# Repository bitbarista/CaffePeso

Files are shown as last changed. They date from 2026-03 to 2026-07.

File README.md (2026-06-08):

# CaffePeso ☕

> [!NOTE]
> **This project is under active development.** Features and hardware design may evolve.
> Feedback and contributions welcome.

<div align="center">

### *Weigh smarter. Pull better.*





**A smart, automated espresso scale with a web interface — no custom PCBs required.**

Armed auto-start • Auto-stop • Smart switch • Live brew ratio • Shot history • Target yield alert • GaggiMate BLE • Beanconqueror BLE • Wi-Fi web UI

[Features](#-features) • [Hardware](#️-hardware) • [3D Print Files](#-3d-print-files) • [Installation](#-installation) • [Documentation](#-documentation) • [Attribution](#-attribution)

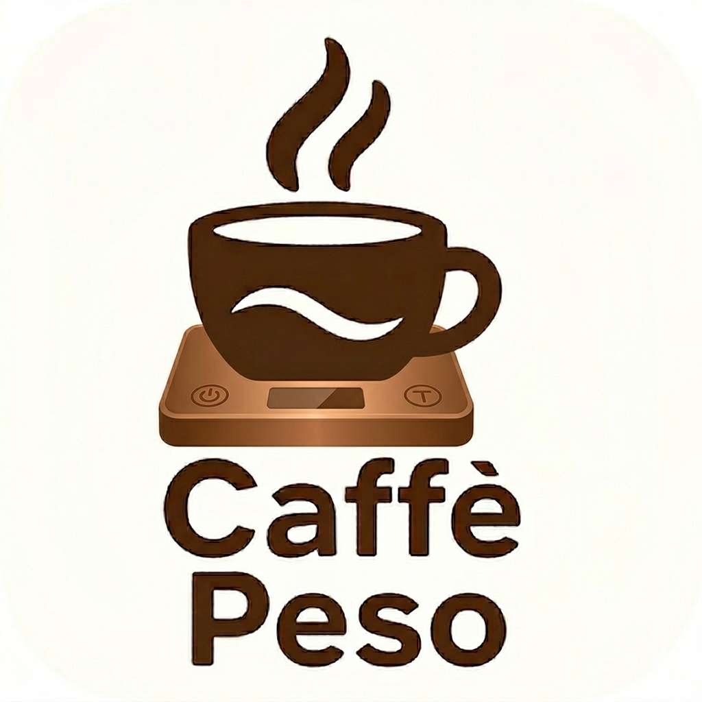
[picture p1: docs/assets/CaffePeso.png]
CaffePeso


</div>

---

## 📖 What is CaffePeso?

CaffePeso is a fork of [WeighMyBru²](https://github.com/031devstudios/weighmybru2) by 031DevStudios, adding brewing automation to an already excellent DIY espresso scale. It runs on an ESP32-S3 and hosts its own web interface over Wi-Fi — no external server or hub required.

It is designed to work alongside [GaggiMate](https://github.com/jniebuhr/gaggimate) via Bluetooth, or as a standalone scale. Inspired by the [EspressiScale](https://www.espressiscale.com) approach, but built from easily sourceable off-the-shelf parts — no custom PCBs.

---

## 📸 Screenshots

<table>
  <tr>
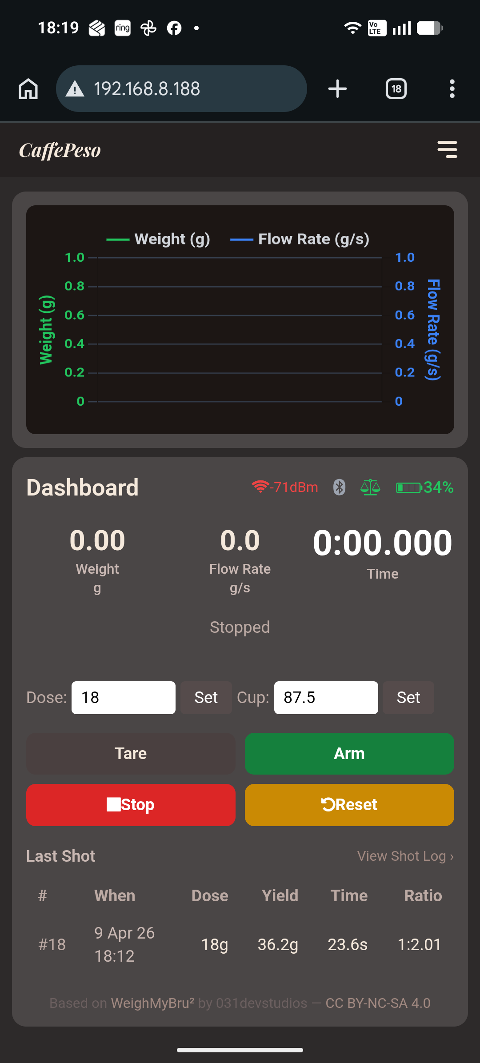
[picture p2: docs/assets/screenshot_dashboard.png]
    <td align="center"><br/><sub>Dashboard</sub></td>
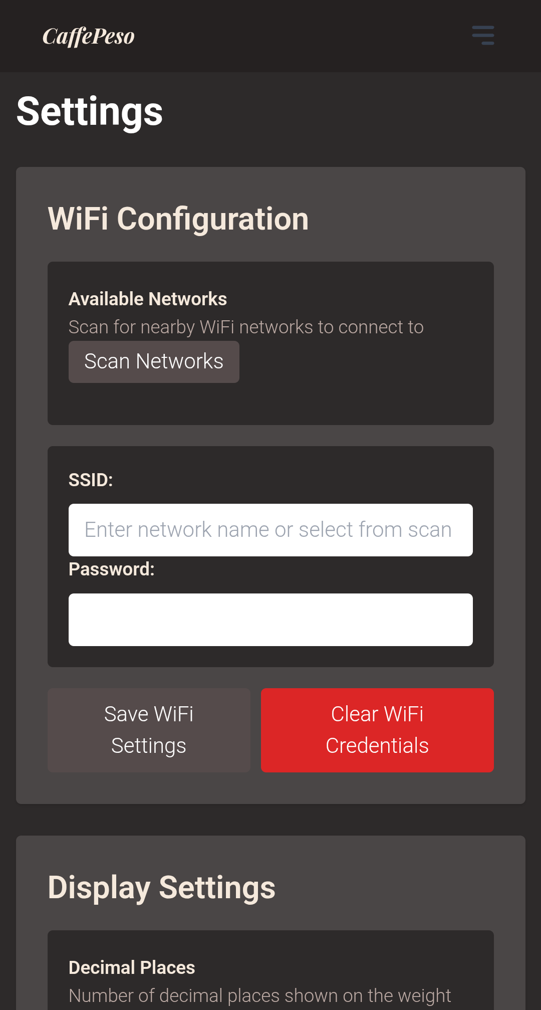
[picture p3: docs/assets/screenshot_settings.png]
    <td align="center"><br/><sub>Settings</sub></td>
  </tr>
  <tr>
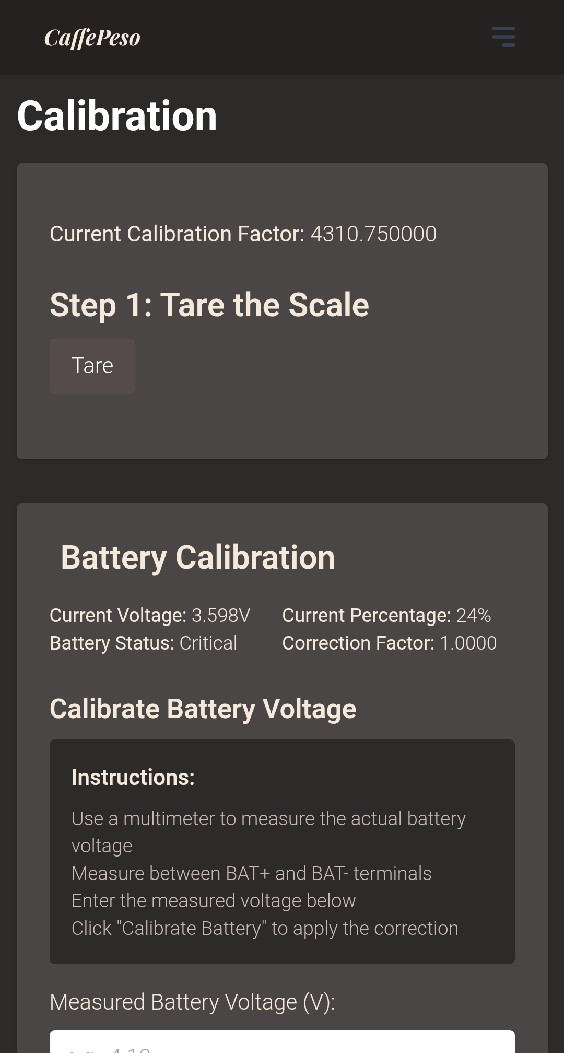
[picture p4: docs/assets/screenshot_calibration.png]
    <td align="center"><br/><sub>Calibration</sub></td>
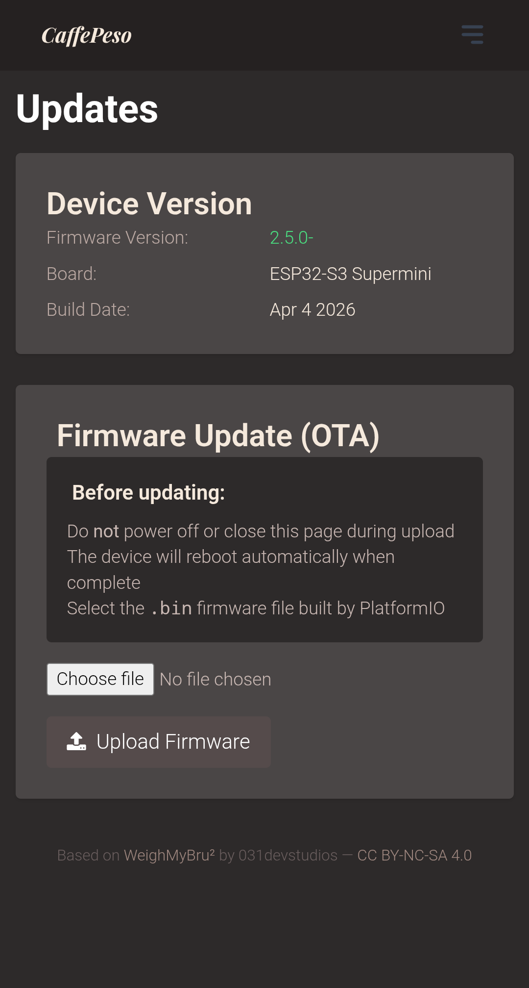
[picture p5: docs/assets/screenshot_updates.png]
    <td align="center"><br/><sub>Updates</sub></td>
  </tr>
  <tr>
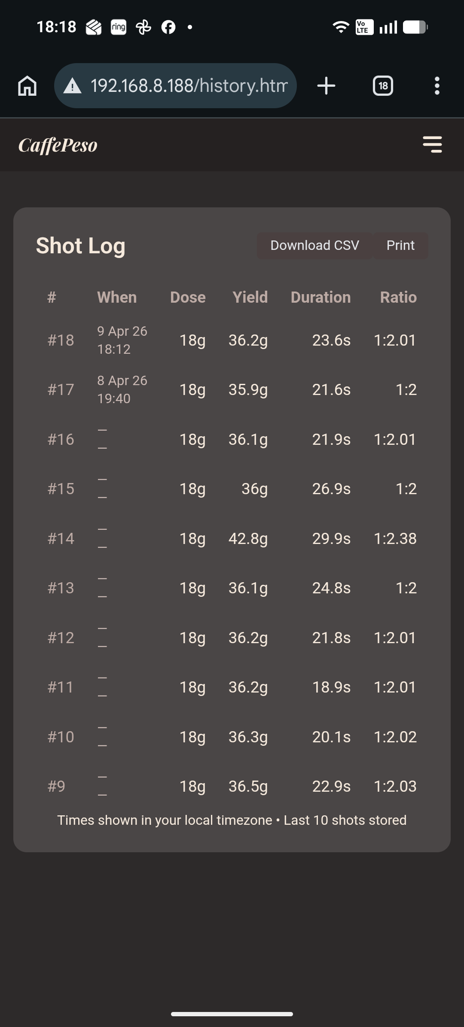
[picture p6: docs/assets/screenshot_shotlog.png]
    <td align="center"><br/><sub>Shot Log</sub></td>
  </tr>
</table>

---

## ✨ Features

### ⏱️ Armed Auto-Start
Hold tare to arm the scale before your shot. The timer starts automatically when the first drip hits the cup — no button press needed at the machine.

### 🔄 Auto-Re-Arm
The scale remembers your cup weight. On the next shot, place the same cup and tap tare — it recognises the cup and arms itself automatically.

### 📊 Live Brew Ratio
Set your dose once. The OLED displays a live 1:X ratio as yield builds in the cup, so you always know where you are in the extraction.

### 🔔 Target Yield Alert
Configure a target ratio (e.g. 1:2.0). When yield approaches your target, the OLED flashes and the web UI turns amber — giving you time to stop the shot.

### 🔊 Audible Beeps (Piezo Buzzer)
An optional piezo buzzer adds sound to the key moments — tare, armed/re-armed, target yield reached, smart-switch stop, low battery, and Bluetooth connect/disconnect. Every beep is individually toggleable in **Settings → Sound**, so you can keep just the cues you want. This is an optional add-on that requires fitting the piezo (see the [wiring guide](docs/USER_GUIDE.md#24-wiring)); CaffePeso is fully functional without it.

### 📜 Shot History
The last 10 shots are automatically saved to non-volatile memory: dose, yield, time, and ratio. Survives reboots and power loss. Displayed in the web UI dashboard.

### 📱 Wi-Fi Web Interface
A full dashboard hosted directly on the ESP32-S3 — calibration, settings, shot history, OTA firmware updates, and real-time graphs. No app required.

### 🛑 Auto-Stop on Flow Cessation

Once flow has been active for at least 8 seconds, the timer stops automatically when flow drops below 0.5 g/s and remains there for 2 seconds. No manual stop needed at the end of a shot.

### 🔌 Smart Switch (Shelly Integration)

> **⚠️ Safety notice:** This feature requires fitting a Shelly relay into your machine's mains electrical circuit. This work involves mains voltage and must only be carried out by a competent person who understands the risks. The authors of this project accept no liability for damage, injury, or death arising from electrical work carried out in connection with this feature. **This is entirely optional — CaffePeso is fully functional without it.**

CaffePeso can automatically stop your espresso machine by controlling a [Shelly](https://www.shelly.com) smart relay fitted inline with the pump or solenoid valve. This does require electrical work inside the machine and should only be carried out by a competent person.

When armed with a dose and target ratio, CaffePeso monitors weight and flow rate during the shot and fires a relay-off command when the projected final yield is about to hit the target:

```
trigger = target_weight − (flow_rate × after_stop_time)
```

The **After-Stop Time (AST)** — the seconds of drip after the pump cuts — is learned automatically from each shot and stored per dose/ratio combination, improving accuracy over time.

A **post-trigger safety interlock** keeps the relay off until you perform a hold-tare, preventing the pump accidentally restarting between shots.

See [Section 14 of the User Guide](docs/USER_GUIDE.md#14-smart-switch-shelly-integration) for setup instructions.

### 🔵 Bluetooth Scale Support
Native Bluetooth scale support for [GaggiMate](https://github.com/jniebuhr/gaggimate) and [Beanconqueror](https://beanconqueror.com). CaffePeso uses the same BLE protocol as WeighMyBru² — GaggiMate's existing WeighMyBru support works with CaffePeso without any changes on either side. Beanconqueror can connect to CaffePeso for real-time weight, tare, and timer control.

---

## 🛠️ Hardware

The hardware is identical to the original WeighMyBru² project. See the [original WeighMyBru² repository](https://github.com/031devstudios/weighmybru2) for:
- Bill of Materials (BOM) with purchase links
- Wiring guides and pin assignments

**Supported boards:**
- ESP32-S3 SuperMini (4 MB flash) — default
- XIAO ESP32S3 (8 MB flash)

---

## 🖨️ 3D Print Files

All enclosure files are included in this repository and available as a single download — no need to navigate anywhere else.



The ZIP contains:

| File | Purpose |
|---|---|
| `WeighMyBru² - Top.3mf` | Main lid — standard walls |
| `WeighMyBru² - Top (0.8mm).3mf` | Main lid — 0.8 mm walls |
| `WeighMyBru² - Bottom.3mf` | Base |
| `WeighMyBru² - Bottom Supported.3mf` | Base, with print supports |
| `WeighMyBru² - Bottom - Piezo.3mf` | Base, piezo cutout — *optional* |
| `WeighMyBru² - ESP32 Clamp.3mf` | ESP32-S3 SuperMini clamp |
| `WeighMyBru² - XAIO Clamp.3mf` | XIAO ESP32S3 clamp |
| `WeighMyBru² - Screen Clamp.3mf` | OLED display clamp |
| `WeighMyBru² - Touch Clamp.3mf` | Touch button clamp |
| `WeighMyBru² - M2 Washer.3mf` | M2 washer spacer |

Most `.3mf` files also have a matching `.step` file for editing in CAD software.

> These files are from the [WeighMyBru²](https://github.com/031devstudios/weighmybru2) project by 031DevStudios and are licensed under [CC BY-NC-SA 4.0](https://creativecommons.org/licenses/by-nc-sa/4.0/).

---

## 📦 Installation

### 🌐 Web-Based (Recommended)

No software installation required — flash directly from your browser:

1. Visit the [flash page](https://bitbarista.github.io/CaffePeso/flash.html)
2. Connect your ESP32 board via USB
3. Click **Install Firmware** and select your board
4. Follow the prompts

✅ No VS Code or PlatformIO needed
✅ Installs firmware + filesystem in one step
✅ Works on Chrome, Edge, and Opera

### 🔧 PlatformIO (Advanced)

Requires VS Code with the PlatformIO extension.

```bash
# Upload firmware (default: esp32s3-supermini)
pio run --target upload

# Upload filesystem (required for web interface)
pio run --target uploadfs

# For XIAO ESP32S3 explicitly:
pio run -e esp32s3-xiao --target upload
pio run -e esp32s3-xiao --target uploadfs
```

> **Important:** Always flash firmware and filesystem using the same environment. Flashing the wrong environment (e.g. xiao firmware onto a supermini) causes a boot crash due to flash size mismatch (4 MB vs 8 MB).

---

## 📚 Documentation

Full user guide: [docs/USER_GUIDE.md](docs/USER_GUIDE.md)

For hardware build guides and video walkthroughs, see the [original project](https://github.com/031devstudios/weighmybru2).

---

## 🤝 Contributing

Contributions welcome — bug fixes, features, and documentation improvements are all appreciated. Please test your changes before submitting a pull request.

---

## 📜 Attribution

This project is a derivative of [WeighMyBru²](https://github.com/031devstudios/weighmybru2) by 031devstudios, licensed under [CC BY-NC-SA 4.0](https://creativecommons.org/licenses/by-nc-sa/4.0/).

Additions in this fork:
- CaffePeso branding — dark warm-brown web UI theme, Playfair Display italic title, OLED splash
- Armed auto-start: hold tare to arm; timer triggers on first drip; auto-re-arms when same cup detected
- Live OLED brew ratio during extraction
- Target yield alert: OLED flashes and web UI turns amber when approaching target ratio
- Cup weight persistence across reboots (NVS)
- Shot history: last 10 shots stored in NVS, displayed in web UI
- Power button redesigned: tap cycles timer (start → pause → reset); hold 1 s = status page; hold 3 s = sleep
- Wi-Fi always-on: toggle removed; device deep-sleeps to save power instead
- Auto-stop on flow cessation: timer stops automatically when espresso flow ends
- Auto-tare on vessel placement: tares automatically when a stable weight is detected (configurable threshold)
- Post-brew idle reset: auto-resets and re-tares after a configurable idle period
- Arm button in web UI: arm/disarm directly from the dashboard without touching the physical button
- Smart switch: predictive Shelly relay control to stop the machine at target yield, with per-dose AST learning and post-trigger safety interlock

This derivative is also released under [CC BY-NC-SA 4.0](https://creativecommons.org/licenses/by-nc-sa/4.0/).

---

## ⚖️ Disclaimer

This project is provided "AS IS" without warranty of any kind. The author makes no representations about suitability, reliability, or fitness for any purpose. Your use is entirely at your own risk. The author shall not be liable for any damages arising from use, including but not limited to direct, indirect, incidental, or consequential damages.

---

## 🙏 Acknowledgments

- **[WeighMyBru²](https://github.com/031devstudios/weighmybru2)** by 031devstudios — the hardware design and original firmware this project is built on (CC BY-NC-SA 4.0)
- **[GaggiMate](https://github.com/jniebuhr/gaggimate)** by jniebuhr — for native BLE scale support
- **[EspressiScale](https://www.espressiscale.com)** — inspiration for the approach

---

<div align="center">

**Built with ☕ by a home espresso enthusiast**

*Not affiliated with any espresso machine manufacturer*

</div>

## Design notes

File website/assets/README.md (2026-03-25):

# Website Assets

This directory contains images and other assets for the CaffePeso website.

## Required Files

Please add these image files to this directory:

### Board Images
- `supermini-board.jpg` - Photo of ESP32-S3 Supermini board (recommended: 400x300px)
- `xiao-board.jpg` - Photo of XIAO ESP32S3 board (recommended: 400x300px)

### Branding
- `logo.png` - CaffePeso logo (recommended: 128x128px or larger)
- `favicon.ico` - Website favicon (16x16px, 32x32px)

## Image Guidelines

### Board Photos
- Use clear, well-lit photos showing the board clearly
- White or light background preferred
- Show the USB connector and any relevant markings
- Crop to focus on the board itself

### Logo
- Transparent background PNG preferred
- High resolution for scalability
- Should work on both light and dark backgrounds

## Optimization

Before uploading to your website, consider optimizing images:

```bash
# Using imagemagick to optimize
convert supermini-board.jpg -quality 85 -resize 400x300 supermini-board.jpg
convert xiao-board.jpg -quality 85 -resize 400x300 xiao-board.jpg

# Using webp for better compression (optional)
cwebp -q 85 supermini-board.jpg -o supermini-board.webp
cwebp -q 85 xiao-board.jpg -o xiao-board.webp
```

## Fallbacks

If you don't have actual board photos yet, you can:

1. Use placeholder images with the board names
2. Find Creative Commons images online
3. Use manufacturer product photos (check licensing)
4. Generate simple graphics with the board names

The website will still function without images - they'll show as empty placeholders.

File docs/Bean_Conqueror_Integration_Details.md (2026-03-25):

# CaffePeso - Bean Conqueror Integration Details

## Current BLE Implementation for Bean Conqueror Integration

### Advertising Information
- **Device Name**: `CaffePeso`
- **Advertising**: Device advertises continuously when not connected

### Service and Characteristic UUIDs
- **Service UUID**: `6E400001-B5A3-F393-E0A9-E50E24DCCA9E`
- **GaggiMate Weight Characteristic UUID**: `6E400002-B5A3-F393-E0A9-E50E24DCCA9E`
  - Properties: READ, NOTIFY, INDICATE
  - Used for: GaggiMate weight data (CaffePeso protocol format)
- **Command Characteristic UUID**: `6E400003-B5A3-F393-E0A9-E50E24DCCA9E`
  - Properties: WRITE, WRITE_NR, NOTIFY
  - Used for: Receiving commands from both apps (tare, timer control)
- **Bean Conqueror Weight Characteristic UUID**: `6E400004-B5A3-F393-E0A9-E50E24DCCA9E`
  - Properties: READ, NOTIFY, INDICATE
  - Used for: Bean Conqueror weight data (simple float format)

### Required API Functions - Implementation Status

#### ✅ Weight Send
- **Status**: ✅ IMPLEMENTED
- **Frequency**: 50ms interval (20 updates/second)
- **Format**: CaffePeso protocol with weight data in grams
- **Precision**: Floating point weight values

#### ✅ Taring
- **Status**: ✅ IMPLEMENTED
- **Command Code**: `0x01`
- **Protocol**: Send `[0x03, 0x0A, 0x01, 0x01, 0x00]` to command characteristic
- **Response**: Confirmation message sent back via weight characteristic
- **Function**: Zeros the scale reading

#### ✅ Timer Start
- **Status**: ✅ IMPLEMENTED
- **Command Code**: `0x02`
- **Protocol**: Send `[0x03, 0x0A, 0x02, 0x01, 0x00]` to command characteristic
- **Response**: Start confirmation `[0x03, 0x0A, 0x02, 0x01, 0x00]`
- **Function**: Starts the brewing timer on CaffePeso

#### ✅ Timer Stop
- **Status**: ✅ IMPLEMENTED
- **Command Code**: `0x03`
- **Protocol**: Send `[0x03, 0x0A, 0x03, 0x01, 0x00]` to command characteristic
- **Response**: Stop confirmation `[0x03, 0x0A, 0x03, 0x01, 0x00]`
- **Function**: Stops the brewing timer on CaffePeso

#### ✅ Timer Reset
- **Status**: ✅ IMPLEMENTED
- **Command Code**: `0x04`
- **Protocol**: Send `[0x03, 0x0A, 0x04, 0x01, 0x00]` to command characteristic
- **Response**: Reset confirmation `[0x03, 0x0A, 0x04, 0x01, 0x00]`
- **Function**: Resets the brewing timer to 0:00.000

## Protocol Details

### Command Message Format
```
[Product_ID, Message_Type, Command, Trigger, Reserved]
```
- **Product_ID**: `0x03` (CaffePeso identifier)
- **Message_Type**: `0x0A` (System command)
- **Command**: Command code (0x01-0x04)
- **Trigger**: `0x01` (Execute command)
- **Reserved**: `0x00` (Future use)

### Weight Data Format
- Sent via weight characteristic notifications
- **Format**: Simple 4-byte float in little-endian byte order
- **Data**: Weight value directly in grams (e.g., 15.67g)
- **Precision**: Full floating-point precision
- **Update Rate**: Automatic notifications every 50ms when connected
- **Byte Layout**: `[float32_little_endian]` (4 bytes total)

### Connection Behavior
- Automatically starts advertising when disconnected
- Stops advertising when connected
- Supports single client connection
- Automatic reconnection support

## Integration Notes for Bean Conqueror

1. **Discovery**: Look for device named "CaffePeso" in BLE scan
2. **Connection**: Connect to service UUID `6E400001-B5A3-F393-E0A9-E50E24DCCA9E`
3. **Weight Subscription**: Subscribe to notifications on `6E400004-B5A3-F393-E0A9-E50E24DCCA9E` (Bean Conqueror specific)
4. **Command Sending**: Write commands to `6E400003-B5A3-F393-E0A9-E50E24DCCA9E`
5. **Timer Control**: All timer functions (start/stop/reset) are available via BLE

### Important: Dual App Support
CaffePeso supports **both Bean Conqueror and GaggiMate simultaneously**:

**Bean Conqueror**:
- Weight data: `6E400004-...` (4-byte float32 little-endian)
- Expected format: Simple float value in grams

**GaggiMate**:
- Weight data: `6E400002-...` (20-byte CaffePeso protocol)
- Expected format: Full protocol with headers and checksums

**Commands**: Both apps share `6E400003-...` for tare and timer commands

## Technical Specifications

- **Platform**: ESP32-S3
- **BLE Stack**: ESP32 Arduino BLE library
- **Update Rate**: 20Hz (50ms intervals)
- **Weight Range**: 0-5000g (depending on load cell)
- **Precision**: 0.1g
- **Timer Precision**: Millisecond accuracy
- **Connection**: Single client BLE connection
- **Power**: Battery operated with monitoring

## Example Usage

```javascript
// Connect to CaffePeso
const device = await navigator.bluetooth.requestDevice({
  filters: [{name: 'CaffePeso'}],
  optionalServices: ['6E400001-B5A3-F393-E0A9-E50E24DCCA9E']
});

// Subscribe to weight notifications
const weightChar = await service.getCharacteristic('6E400002-B5A3-F393-E0A9-E50E24DCCA9E');
await weightChar.startNotifications();

// Send tare command
const commandChar = await service.getCharacteristic('6E400003-B5A3-F393-E0A9-E50E24DCCA9E');
await commandChar.writeValue(new Uint8Array([0x03, 0x0A, 0x01, 0x01, 0x00]));

// Send timer start command
await commandChar.writeValue(new Uint8Array([0x03, 0x0A, 0x02, 0x01, 0x00]));
```

## Relevant Source Files

- `include/BluetoothScale.h` - BeanConquerorCommand enum and method declarations
- `src/BluetoothScale.cpp` - Weight streaming and command handling implementation
- `src/main.cpp` - Display reference for timer control

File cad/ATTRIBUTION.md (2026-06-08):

---
**3D Enclosure Files — Attribution Notice**

These CAD files are sourced from the [WeighMyBru²](https://github.com/031devstudios/weighmybru2) project by [031DevStudios](https://github.com/031devstudios).

Except where noted below, they are reproduced here unchanged for ease of access and are licensed under the same terms as the original:

**[Creative Commons Attribution-NonCommercial-ShareAlike 4.0 International (CC BY-NC-SA 4.0)](https://creativecommons.org/licenses/by-nc-sa/4.0/)**

You are free to share and adapt these files for non-commercial purposes, provided you give appropriate credit and distribute any derivatives under the same licence.

**Modifications:**

- `WeighMyBru² - Bottom - Piezo.3mf` is a derivative of the original `Bottom` model, modified for the CaffePeso project to add a cutout for the optional piezo buzzer. It is shared under the same CC BY-NC-SA 4.0 licence.

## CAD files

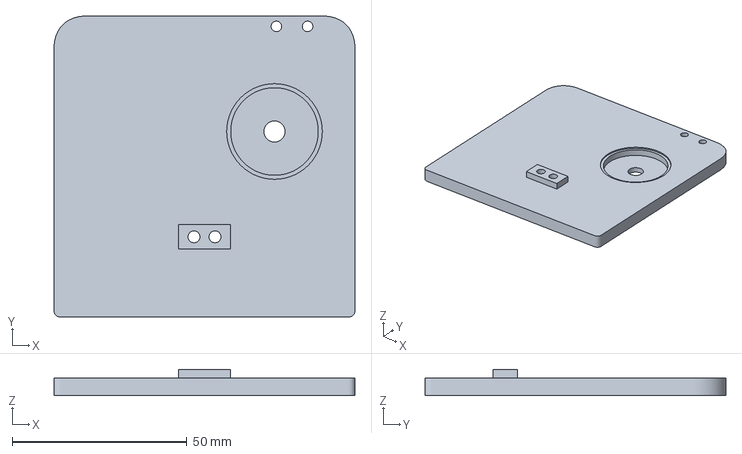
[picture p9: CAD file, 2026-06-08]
cad/3mf/WeighMyBru² - Bottom - Piezo.3mf
86.0 x 86.0 x 7.50 mm

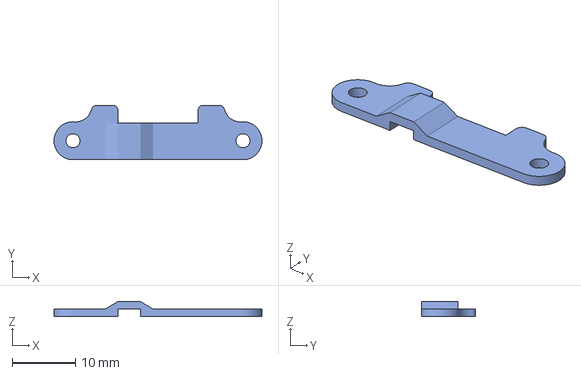
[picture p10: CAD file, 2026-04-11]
cad/3mf/WeighMyBru² - XAIO Clamp.3mf
32.8 x 8.60 x 2.40 mm

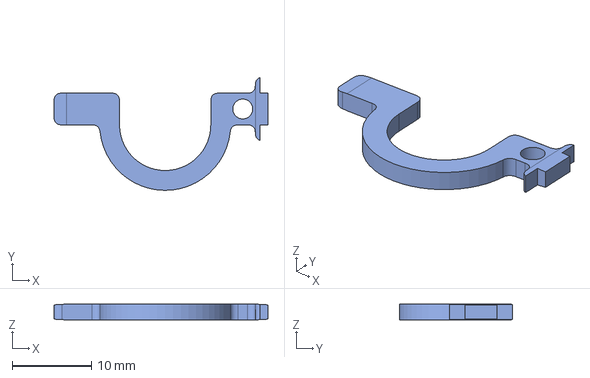
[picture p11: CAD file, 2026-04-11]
cad/step/WeighMyBru² - Touch Clamp.step
26.9 x 14.2 x 2.00 mm

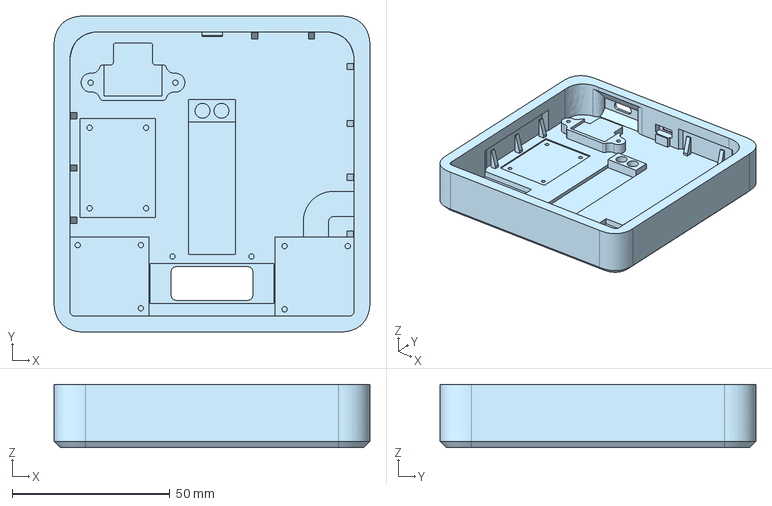
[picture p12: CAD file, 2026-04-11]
cad/step/WeighMyBru² - Top.step
100.0 x 100.0 x 20.0 mm

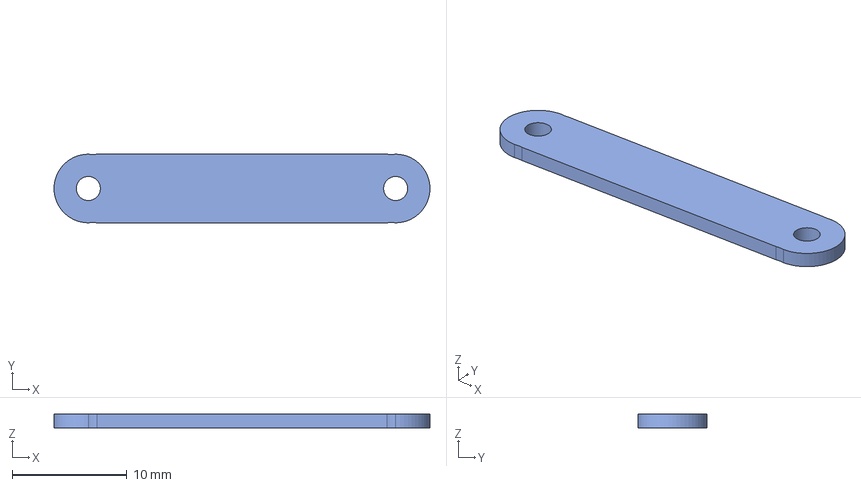
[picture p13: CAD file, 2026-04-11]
cad/step/WeighMyBru² - ESP32 Clamp.step
32.8 x 6.00 x 1.20 mm

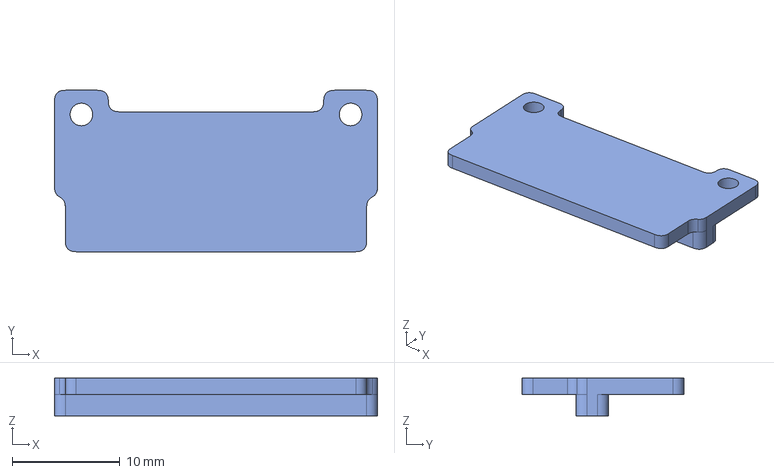
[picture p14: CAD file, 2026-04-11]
cad/step/WeighMyBru² - Screen Clamp.step
30.0 x 15.0 x 3.50 mm

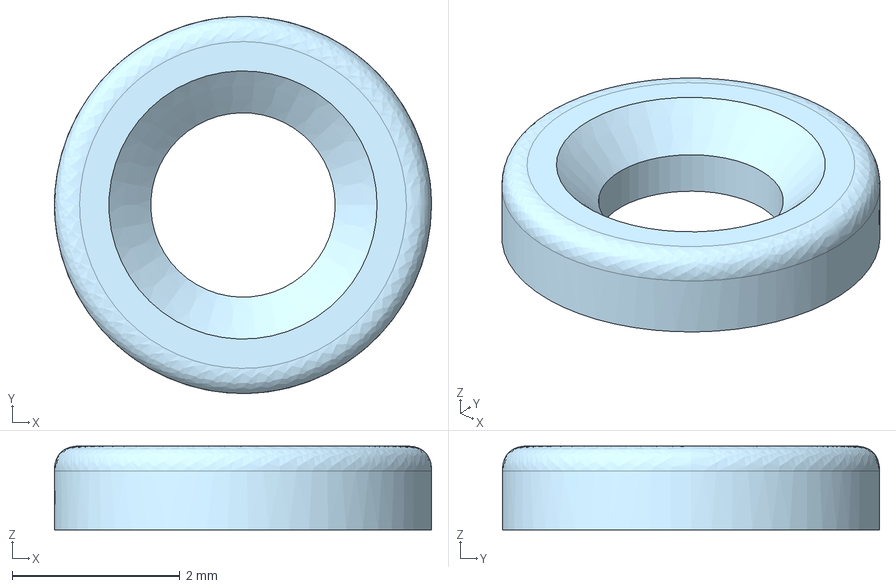
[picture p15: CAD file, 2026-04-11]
cad/step/WeighMyBru² - M2 Washer.step
4.50 x 4.50 x 1.00 mm

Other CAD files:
cad/step/WeighMyBru² - Bottom Supported.step
cad/step/WeighMyBru² - Top (0.8mm).step
cad/step/WeighMyBru² - Bottom.step
cad/3mf/WeighMyBru² - Bottom Supported.3mf
cad/3mf/WeighMyBru² - Bottom.3mf
cad/3mf/WeighMyBru² - ESP32 Clamp.3mf
cad/3mf/WeighMyBru² - M2 Washer.3mf
cad/3mf/WeighMyBru² - Screen Clamp.3mf
cad/3mf/WeighMyBru² - Top (0.8mm).3mf
cad/3mf/WeighMyBru² - Top.3mf
cad/3mf/WeighMyBru² - Touch Clamp.3mf

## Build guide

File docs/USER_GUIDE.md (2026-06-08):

# CaffePeso User Guide

**Version 2.4.3**

---

*Weigh smarter. Pull better.*

---

## Table of Contents

1. [Introduction](#1-introduction)
2. [Hardware Overview](#2-hardware-overview)
3. [First-Time Setup](#3-first-time-setup)
4. [Physical Controls](#4-physical-controls)
5. [OLED Display](#5-oled-display)
6. [Web Interface](#6-web-interface)
7. [Brewing Workflows](#7-brewing-workflows)
8. [Brew Automation Features](#8-brew-automation-features)
9. [Settings Reference](#9-settings-reference)
10. [Calibration](#10-calibration)
11. [Firmware Updates](#11-firmware-updates)
12. [Power and Battery](#12-power-and-battery)
13. [GaggiMate Bluetooth Integration](#13-gaggimate-bluetooth-integration)
14. [Smart Switch (Shelly Integration)](#14-smart-switch-shelly-integration)
15. [Troubleshooting](#15-troubleshooting)

---

## 1. Introduction

CaffePeso is a smart espresso scale built on the ESP32-S3 microcontroller. It combines a precision load cell, a live OLED display, and a Wi-Fi web interface to give you real-time weight, flow rate, timer, and brew ratio — all in a compact, battery-powered unit that sits under your cup.

It is designed to work seamlessly at the espresso machine without requiring a phone or app. Every parameter you need to pull a consistent shot is either visible on the OLED or accessible through a browser on your home network.

**Key capabilities:**

- Real-time weight display with configurable decimal places
- Brew timer with automatic start on first drip (armed auto-start)
- Live flow rate (g/s) and brew ratio (1:X)
- Target yield alert — OLED flashes when approaching your target
- Shot history — last 10 shots stored through power cycles
- Cup weight auto re-arm — recognises your cup and arms itself for the next shot
- Auto-tare on vessel placement
- Auto-stop when espresso flow ceases
- Wi-Fi web interface with real-time graph, calibration, settings, and OTA updates
- GaggiMate Bluetooth scale compatibility

---

## 2. Hardware Overview

### 2.1 Supported Boards

| Board | Flash | Notes |
|---|---|---|
| ESP32-S3 SuperMini | 4 MB | Default — recommended |
| XIAO ESP32S3 | 8 MB | Alternative |

### 2.2 Pin Assignments

| Function | GPIO | Notes |
|---|---|---|
| HX711 Data | 5 | Load cell amplifier data |
| HX711 Clock | 6 | Load cell amplifier clock |
| Tare button | 4 | Capacitive touch module |
| Sleep/timer button | 3 | Capacitive touch module |
| Battery voltage | 7 | ADC via 2× 100 kΩ voltage divider |
| I²C SDA (display) | 8 | SSD1306 OLED |
| I²C SCL (display) | 9 | SSD1306 OLED |

### 2.3 Bill of Materials

| Qty | Component |
|-----|---|
| 1 | 500 g I-shaped mini load cell |
| 1 | HX711 load cell amplifier module |
| 1 | ESP32-S3 SuperMini (or XIAO ESP32S3) |
| 1 | 0.91″ SSD1306 OLED display (128×32, I²C) |
| 2 | Capacitive touch pad modules |
| 1 | 800 mAh Li-ion battery |
| 1 | JST-PH 2.0 male connector |
| 1 | 5 mm slide switch (power) |
| 2 | 100 kΩ 1% resistors (battery voltage divider) |
| 1 | 27 mm piezo disc (~4.2 kHz resonant) — *optional* |
| 2 | 150 Ω resistors (piezo series, one per lead) — *optional* |
| 4 | Self-adhesive rubber feet |

Purchase links for all components are available in the [WeighMyBru² repository](https://github.com/031devstudios/weighmybru2) — the hardware is identical.

### 2.4 Wiring

GPIO pin numbers are identical on both supported boards. The physical pin *locations* differ — refer to the pinout diagram for your specific board when connecting wires.

#### HX711 Load Cell Amplifier

| HX711 Pin | Connect to |
|---|---|
| VCC | 3.3 V |
| GND | GND |
| DT | GPIO 5 |
| SCK | GPIO 6 |

Connect the load cell wires to the HX711 E+/E−/A+/A− terminals. Load cell wire colours vary by manufacturer — consult the datasheet for your specific cell (typically: red = E+, black = E−, white = A−, green = A+).

#### OLED Display (SSD1306, I²C)

| Display Pin | Connect to |
|---|---|
| VCC | 3.3 V |
| GND | GND |
| SDA | GPIO 8 |
| SCL | GPIO 9 |

#### Capacitive Touch Pads

| Touch Pad | Signal Pin | Connect to |
|---|---|---|
| Tare button | SIG | GPIO 4 |
| Sleep/timer button | SIG | GPIO 3 |

Both touch pads share 3.3 V and GND.

#### Battery Voltage Divider and Power Switch

The battery voltage is monitored via a resistor divider on GPIO 7 (ADC), halving the voltage to fall within the 3.3 V ADC range. The divider connects directly to Battery (+) — before the switch — so the low-battery check can run at boot. Use 1% tolerance resistors for accurate readings.

The slide switch is wired in series between Battery (+) and the VCC rail. When open, the device is fully powered off.

#### Piezo Buzzer (differential drive)

> The piezo buzzer is **optional** — CaffePeso is fully functional without it. It adds audible beeps for events such as tare, target yield reached, and arming (each individually toggleable in **Settings → Sound**).

| Piezo Lead | Connect to |
|---|---|
| Lead 1 | 150 Ω resistor → GPIO 1 |
| Lead 2 | 150 Ω resistor → GPIO 2 |

The 27 mm piezo disc is driven *differentially* (BTL): GPIO 1 and GPIO 2 swing in antiphase, putting roughly twice the voltage across the disc for a noticeably louder tone. A **150 Ω resistor in series with each lead is required.** The bare disc is capacitive (~15–30 nF) and on each switching edge presents a near short-circuit to the GPIO pins; this sags the ESP32-S3's on-board regulator enough to trigger a brown-out reset. The two series resistors limit the inrush current and eliminate the resets. Polarity is not significant, and no transistor is needed (drive current is only a few mA).

#### Complete Circuit Schematic

```
+=========================================================================+
|                       CaffePeso -- Circuit Schematic                    |
+=========================================================================+

POWER
                              .-- [SW1 Power Switch] ----- VCC (3.3V)
  Battery (+) --------+------'
                      |
                      +-- [R1 100k] --+-- [R2 100k] ------- GND
                                      |
                                    GPIO7 (ADC)

  Battery (-) -------------------------------------------------- GND

LOAD CELL & HX711

  Load Cell             HX711 Module               ESP32-S3
  +------------+       +-------------+
  | E+  (RED)  |--E+---| E+  VCC     |------------ 3.3V
  | E-  (BLK)  |--E----|  E- GND     |------------ GND
  | A-  (WHT)  |--A----|  A- DT      |------------ GPIO5
  | A+  (GRN)  |--A+---|  A+ SCK     |------------ GPIO6
  +------------+       +-------------+

OLED DISPLAY (SSD1306, 0.91" I2C)

  +-------+
  |  VCC  |------ 3.3V
  |  GND  |------ GND
  |  SDA  |------ GPIO8
  |  SCL  |------ GPIO9
  +-------+

TOUCH PADS (TTP223B capacitive modules)

  Tare Button                    Sleep / Timer Button
  +-------+                      +-------+
  |  VCC  |------ 3.3V           |  VCC  |------ 3.3V
  |  GND  |------ GND            |  GND  |------ GND
  |  SIG  |------ GPIO4          |  SIG  |------ GPIO3
  +-------+                      +-------+

PIEZO BUZZER (27mm disc, differential / BTL drive)

  ESP32-S3
  GPIO1 ----[ R3 150R ]----+
                           |
                          (+)
                          === 27mm piezo disc
                          (-)
                           |
  GPIO2 ----[ R4 150R ]----+

  GPIO1 and GPIO2 are driven in antiphase (~2x voltage swing across
  the disc => louder). The 150R series resistors are REQUIRED: they
  limit the capacitive inrush current that would otherwise sag the
  regulator and brown-out / reset the board. No transistor needed.

All GND labels share a common ground.
All 3.3V labels connect to the VCC rail (Battery+ -> SW1 ->
ESP32-S3 built-in regulator).
```

---

## 3. First-Time Setup

### 3.1 Flash the Firmware

**Recommended — browser-based (no software required):**

1. Visit the [CaffePeso flash page](https://bitbarista.github.io/CaffePeso/flash.html) in Chrome, Edge, or Opera.
2. Connect your ESP32-S3 board via USB.
3. Click **Install Firmware**, select your board type (SuperMini or XIAO), and follow the prompts.
4. Both firmware and web interface files are installed in a single step.

**Alternative — PlatformIO:**

```bash
# Flash firmware
pio run -e esp32s3-supermini --target upload

# Flash web interface files (required separately)
pio run -e esp32s3-supermini --target uploadfs
```

> **Important:** Always use the same environment for firmware and filesystem. Mixing environments (e.g. xiao filesystem with supermini firmware) causes a crash at boot due to flash size differences.

### 3.2 Connect to Wi-Fi

On first boot, CaffePeso starts in **Access Point mode**:

1. The OLED displays the AP IP address (`192.168.4.1`).
2. Connect your phone or computer to the Wi-Fi network **CaffePeso** (no password).
3. Open a browser and navigate to `http://192.168.4.1`.
4. Go to **Settings → Wi-Fi Configuration**.
5. Either scan for networks or type your SSID and password, then click **Save Wi-Fi Settings**.
6. The device connects and switches to Station mode. The OLED displays the new IP address.
7. Reconnect your device to your home network and navigate to the displayed IP address.

> **Tip:** Assign a static DHCP lease to CaffePeso's MAC address on your router so the IP address never changes.

### 3.3 Calibrate the Scale

Before first use, the scale must be calibrated to your specific load cell. See [Section 10 — Calibration](#10-calibration) for the full procedure.

### 3.4 Set Your Dose Weight

Open the **Dashboard** in the web interface and enter your coffee dose in the **Dose** field, then click **Set**. This value is persisted through power cycles and is used for live brew ratio display and shot history logging.

---

## 4. Physical Controls

CaffePeso has two capacitive touch buttons. They are labelled here as **Tare** and **Timer**.

### 4.1 Tare Button

The Tare button zeros the scale and, with a longer hold, arms the auto-start timer.

| Gesture | Action |
|---|---|
| **Tap** | Zero the scale. Resets the timer if not mid-brew. |
| **Hold ~0.5 s** | OLED shows **"Taring…"** — keep holding as a prompt. |
| **Hold ~1.5 s** | OLED shows **"Release!"** |
| **Release after 1.5 s** | Tare + arm. Saves cup weight, arms for auto-start. OLED shows **"Armed"** (inverted display). |

After a tap-tare, the scale waits ~1.5 seconds before executing the tare. This brief delay gives you time to lift your hand cleanly so press force does not skew the zero reference.

After a hold-tare (arm), the scale waits ~0.3 seconds after release before reading the cup weight, for the same reason.

### 4.2 Timer Button

The Timer button controls the brew timer and puts the device to sleep.

| Gesture | Action |
|---|---|
| **Tap** | Cycle timer: **Stopped → Running → Paused → Stopped** |
| **Hold 3 s** | Start sleep countdown (3–2–1 on OLED). Touch again during countdown to cancel. |

**Waking from sleep:** Touch either button. The device boots in a few seconds.

### 4.3 Factory Reset

To clear all Wi-Fi credentials, hold the **Tare** button while powering on (slide the power switch whilst keeping the tare pad touched). The OLED flashes and the device restarts in Access Point mode.

---

## 5. OLED Display

The 0.91″ SSD1306 display (128×32 pixels) shows a two-row layout during normal operation.

### 5.1 Main Display Layout

```
┌────────────────────────────┐
│  45.3g              BT [■■]│  ← weight (large), status icons top-right
│  0:28.5   2.1 g/s   1:2.2  │  ← timer, flow rate, ratio (or avg flow)
└────────────────────────────┘
```

**Top row:** Current weight in grams. Size scales with the value.

**Bottom row (during brew):** Timer elapsed time · Flow rate (g/s) · Live brew ratio (1:X)

**Bottom row (after brew):** Timer elapsed time · Average flow rate for the shot

**Status icons (top right):**
- **BT** — Bluetooth connected to GaggiMate
- **Battery** — 3-segment indicator. Flashes when low.

### 5.2 OLED Messages

| Message | Trigger |
|---|---|
| **Taring…** | Tare button held past 0.5 s — keep holding |
| **Release!** | Tare button held past 1.5 s — release now |
| **Scale Tared** (normal) | Tap-tare completed |
| **Scale Tared** (inverted) | Auto-tare or cup-weight auto re-arm tare completed |
| **Armed** (inverted) | Hold-tare arm completed, or auto re-arm triggered |
| **Battery Low** | Battery voltage below threshold at boot |
| **Going to Sleep** | Sleep countdown finished, entering deep sleep |
| **Sleep Cancelled** | Timer button touched during sleep countdown |
| Countdown **3… 2… 1…** | Sleep countdown in progress |

An inverted display (white background, black text) is used whenever an automatic tare or arm fires — visually distinguishing automated actions from manual ones.

---

## 6. Web Interface

The web interface is served directly from the ESP32-S3 over Wi-Fi. Open a browser and navigate to the device IP address shown on the OLED at boot.

> **Tip:** The interface can be installed as a Progressive Web App (PWA) on Android and iOS — use "Add to Home Screen" from your browser menu for quick access.

### 6.1 Dashboard

The Dashboard is the main working screen during brewing.

**Real-time metrics (updated 10 times per second):**

| Field | Description |
|---|---|
| **Weight** | Current weight in grams |
| **Flow Rate** | Rate of weight increase in g/s |
| **Time** | Elapsed brew time (mm:ss.mmm) |
| **Brew Ratio** | Live 1:X ratio based on dose and current yield |
| **Avg Flow Rate** | Average flow rate for the completed shot (shown after brew) |

**Status indicators (header bar):**
- Wi-Fi signal strength and quality
- Bluetooth connection status
- Scale connection status
- Battery level and percentage

**Live graph:** Weight and flow rate plotted over time. Recording follows the timer — starts when the timer starts, stops when it stops.

**Dose and Cup Weight inputs:** Enter your coffee dose and cup weight here, then click **Set**. Both values are persisted through reboots.

**Action buttons:**

| Button | Action |
|---|---|
| **Tare** | Zero the scale via the web interface |
| **Arm** / **Disarm** | Arm or disarm the auto-start timer |
| **Stop** | Stop the brew timer |
| **Reset** | Reset the timer to 00:00 |

**Shot History:** The last 10 shots are shown in a table with dose, yield, time, and ratio. Click **Clear** to erase the history.

**Target yield alert:** When the current weight approaches the target yield (dose × target ratio), the weight display turns amber and the OLED flashes briefly.

### 6.2 Calibration

See [Section 10 — Calibration](#10-calibration).

### 6.3 Settings

All persistent settings are configured here. Settings are grouped into sections — see [Section 9 — Settings Reference](#9-settings-reference) for full details.

### 6.4 Updates

Shows the current firmware version, board, and build date. Provides one-click update from GitHub and manual OTA firmware upload. See [Section 11 — Firmware Updates](#11-firmware-updates).

---

## 7. Brewing Workflows

### 7.1 Basic Manual Workflow

1. Place your cup on the scale.
2. **Tap Tare** to zero.
3. Start your espresso machine.
4. **Tap Timer** when the first drip hits the cup.
5. **Tap Timer** again to stop when you reach your target weight.
6. The OLED shows elapsed time and average flow rate.

### 7.2 Armed Auto-Start Workflow

This is the recommended workflow. The timer starts automatically on the first drip — no button press at the machine needed.

1. Place your cup on the scale.
2. **Hold Tare for ~1.5 s** until you see **"Release!"**, then release.
   - The scale tares with the cup weight zeroed.
   - The cup weight is saved.
   - The OLED shows **"Armed"** (inverted display).
3. Start your espresso machine.
4. The timer starts automatically when the first drip exceeds ~1 g.
5. Stop the pump manually when you reach your target weight.
   - Or enable **Target Yield Alert** to get a visual cue.
   - Or enable **Auto-Stop on Flow Cessation** to stop the timer automatically.

### 7.3 Repeated Shots — Auto Re-Arm Workflow

With **Cup Weight Auto Re-arm** enabled (the default), CaffePeso recognises your cup and arms itself automatically for the next shot.

**After the first shot (armed auto-start):**

1. Remove the cup when the shot is done.
2. Knock out the spent puck, rinse the portafilter, grind and tamp a fresh dose.
3. Place the same cup back on the scale.
   - The scale detects the cup weight, tares, and arms — OLED shows **"Armed"** (inverted).
4. Start the next shot. The timer starts on the first drip.

This works because CaffePeso remembers the cup weight from the hold-tare. It compares the weight of whatever is placed on the scale against the saved value, and arms automatically when they match.

> **Note:** Auto re-arm requires a step-change in weight (the cup being placed on the scale) to fire. Milk being gradually poured through the cup weight window does not trigger re-arm. This prevents false triggers during milk-based drink preparation.

### 7.4 Tap-Tare Workflow (No Auto Re-arm)

If you prefer to arm manually each time:

1. Tap Tare to zero the scale with the cup on it.
2. Press **Arm** in the web interface, or hold-tare, to arm.
3. Proceed as in the armed auto-start workflow.

---

## 8. Brew Automation Features

### 8.1 Armed Auto-Start

When armed, the timer starts automatically when weight increases above ~1 g and stays there for 500 ms. This captures the precise moment the first drip hits the cup without requiring a button press at the machine.

**To arm:** Hold the Tare button for ~1.5 s until **"Release!"** appears, then release. The OLED confirms with **"Armed"** on an inverted display.

**To arm via the web interface:** Click the **Arm** button on the Dashboard.

**Arm timeout:** If no drip is detected within 2 minutes of arming, the scale disarms automatically.

### 8.2 Cup Weight Auto Re-Arm

Automatically arms the scale when the saved cup weight is placed on it, eliminating the need to manually arm between shots.

**Requirements:**
- A cup weight must have been saved by at least one hold-tare.
- **Cup Weight Auto Re-arm** must be enabled in Settings → Brew Automation.

**Detection logic:**
The scale monitors weight against the saved cup weight (±5 g window) and requires a step-change of at least 8 g per update cycle to count as a cup placement. This prevents a gradual pour (e.g. milk) from falsely triggering re-arm.

**Re-arm paths:**
- **Tared path:** After a tap-tare (scale reads 0 g), placing the cup reads approximately the saved cup weight. Step-change detected → stable 200 ms → auto re-arm.
- **Direct path:** After removing the cup (scale goes very negative), placing it back directly (without tap-taring) reads ~0 g against the original cup-tare reference. Scale went negative → weight returns near 0 → auto re-arm.

### 8.3 Auto-Stop on Flow Cessation

When enabled, the timer stops automatically when espresso flow ceases — no manual stop needed at the end of a shot.

**How it works:**
- Flow must first exceed 1.0 g/s (confirming extraction is underway).
- Flow must then drop below 0.5 g/s and remain there for 2 seconds.
- This check does not engage within the first 8 seconds of the brew (prevents false stops during slow starts).

Enable in **Settings → Brew Automation → Auto-Stop on Flow Cessation**.

### 8.5 Auto-Tare on Vessel Placement

When enabled, the scale automatically tares whenever a stable weight above the configured threshold is placed on it — useful if you always use the same vessel and don't want to think about taring.

**How it works:**
- When a weight above the threshold is detected, a 600 ms stability timer starts.
- If the weight remains stable for 600 ms, the scale tares automatically.
- The OLED shows **"Scale Tared"** on an inverted display (same visual cue as armed auto-start).
- Auto-tare does not re-fire mid-brew when yield crosses the same threshold — it locks after firing and resets only when the vessel is removed (scale reads negative).

**Interaction with Cup Weight Auto Re-arm:** When both features are enabled, the auto re-arm fires first (200 ms stability requirement vs 600 ms for auto-tare). The tracked cup triggers re-arm, not auto-tare. Other vessels trigger auto-tare normally.

Enable in **Settings → Brew Automation → Auto-Tare on Vessel Placement**.

Configure the **Minimum Weight to Trigger** (default: 20 g) to suit your lightest vessel.

### 8.6 Post-Brew Idle Reset

After a brew finishes (timer paused), if no weight change is detected for a configurable period, the scale auto-resets and re-tares — ready for the next drink without intervention.

Enable in **Settings → Brew Automation → Post-Brew Idle Reset**.

Configure the **Idle Timeout** (5–300 seconds, default 30 s).

> **Note:** If Cup Weight Auto Re-arm is enabled, the idle reset skips the re-tare step — re-taring would corrupt the cup weight reference and prevent auto re-arm from recognising the cup.

### 8.7 Target Yield Alert

When a dose and target ratio are configured, the scale alerts you as the brew approaches the target yield.

- The **weight display on the Dashboard turns amber** when current weight approaches the target.
- The **OLED flashes** (inverts briefly) at the target weight.

Configure in **Settings → Brew Automation → Target Yield Ratio**.

Set the ratio as a decimal multiplier — e.g. `2.0` for a 1:2 ratio (18 g dose → 36 g yield), `2.5` for a 1:2.5 ratio.

Set to `0` to disable.

---

## 9. Settings Reference

All settings are accessed via the web interface at **Settings**.

### 9.1 Wi-Fi Configuration

| Setting | Description |
|---|---|
| **SSID** | Your home Wi-Fi network name |
| **Password** | Your Wi-Fi password |
| **Scan Networks** | Scan for nearby networks and select from a list |
| **Clear Wi-Fi Credentials** | Remove stored credentials and return to AP mode |

After saving, the device connects to the new network immediately. If connection fails, it returns to AP mode.

### 9.2 Display Settings

| Setting | Values | Default | Description |
|---|---|---|---|
| **Decimal Places** | 0, 1, 2 | 1 | Number of decimal places shown on the OLED weight display |

### 9.3 Filtering Settings

These control how the scale readings are processed. The defaults are suitable for most setups and rarely need adjustment.

| Setting | Range | Default | Description |
|---|---|---|---|
| **Brewing Detection Threshold** | 0.05–1.0 g | 0.15 g | Weight change required to detect active brewing |
| **Stability Timeout** | 500–10000 ms | 2000 ms | Time before returning to stable (average) filter mode |
| **Brewing Mode Samples** | 1–50 | 3 | Median filter sample count during brewing |
| **Stable Mode Samples** | 1–50 | 5 | Average filter sample count when stable |

### 9.4 Sleep Settings

| Setting | Range | Default | Description |
|---|---|---|---|
| **Auto Sleep** | On/Off | On | Enable sleep after a period of inactivity |
| **Timeout Duration** | 1–60 min | 10 min | Time with no weight change or button press before sleep starts |

Weight changes of more than 0.5 g reset the inactivity timer. Button presses also reset it.

### 9.5 Brew Automation

| Setting | Type | Default | Description |
|---|---|---|---|
| **Cup Weight Auto Re-arm** | Toggle | On | Automatically arm when the saved cup weight is placed on the scale |
| **Auto-Tare on Vessel Placement** | Toggle | Off | Automatically tare when a stable weight is placed |
| **Minimum Weight to Trigger** (auto-tare) | 5–500 g | 20 g | Lightest vessel that triggers auto-tare |
| **Post-Brew Idle Reset** | Toggle | Off | Auto-reset after brew if no weight change |
| **Idle Timeout** | 5–300 s | 30 s | Seconds of inactivity before idle reset fires |
| **Auto-Stop on Flow Cessation** | Toggle | Off | Stop timer automatically when flow ends |
| **Target Yield Ratio** | 0–20 | 0 | Target ratio for yield alert (0 = disabled) |

---

## 10. Calibration

### 10.1 Scale Calibration

The scale must be calibrated once after assembly with a known reference weight. Re-calibrate if readings drift noticeably over time.

**You will need:** A known reference weight (e.g. 100 g calibration weight or any item with a known mass).

**Procedure:**

1. Navigate to **Calibration** in the web interface.
2. Ensure the scale platform is empty.
3. Click **Tare** (Step 1). Wait for confirmation.
4. Place your known reference weight on the scale.
5. Enter the exact weight in grams in the **Known Weight** field (Step 2).
6. Click **Calibrate**. The new calibration factor is applied immediately.
7. **Optionally** — verify accuracy with a second different known weight (Step 3). The result is shown as measured vs expected with a pass/recalibrate rating.

The calibration factor is stored in non-volatile memory and survives reboots.

### 10.2 Battery Calibration

The battery voltage is read through a voltage divider and may have a small offset due to component tolerances. Calibrating it ensures accurate battery percentage readings.

**You will need:** A multimeter.

**Procedure:**

1. Navigate to **Calibration → Battery Calibration** in the web interface.
2. Note the **Current Voltage** displayed.
3. Use a multimeter to measure the actual battery voltage at the BAT+ and BAT− terminals.
4. Enter the measured voltage in the **Measured Battery Voltage** field.
5. Click **Calibrate Battery**.

The correction factor is applied and stored. Future readings use this correction automatically.

---

## 11. Firmware Updates

### 11.1 Update from GitHub (Recommended)

The easiest way to update. CaffePeso can download and install the latest release directly from GitHub — no files to download manually, no USB required.

1. Ensure the device is connected to Wi-Fi (STA mode, not AP-only).
2. Navigate to **Updates** in the web interface.
3. Click **Check for Updates**. The device fetches the latest release manifest from GitHub and compares it to the running version.
4. If an update is available, click **Update from GitHub**.
5. Two progress bars show firmware and web interface download progress separately.
6. The device reboots automatically when both are complete. The page polls for reconnection and confirms the new version.

> **Important:** Do not close the browser tab or power off the device during the update. The download typically takes 20–40 seconds depending on your connection.

### 11.2 Manual OTA Update

If you have a specific `.bin` file (e.g. a development build) you can upload it directly.

1. Navigate to **Updates** in the web interface.
2. Click **Choose File** and select the `.bin` firmware file.
3. Click **Upload Firmware**.
4. A progress bar shows upload progress.
5. The device reboots automatically when complete.

> **Note:** Manual upload only replaces the firmware binary. If the web interface files also need updating, use the GitHub update method or a full reflash.

### 11.3 Web-Based Flash (Full Reflash)

For a complete reinstall of both firmware and filesystem (web interface files), use the [flash page](https://bitbarista.github.io/CaffePeso/flash.html) — requires a USB connection to a computer running Chrome, Edge, or Opera.

---

## 12. Power and Battery

### 12.1 Power Switch

The slide switch on the enclosure cuts power to the entire device. Use it to fully power off when the scale is not in use for an extended period.

### 12.2 Sleep Mode

CaffePeso uses ESP32 deep sleep to conserve battery. In deep sleep, current draw drops to ~10 µA. The OLED turns off and Wi-Fi disconnects.

**Entering sleep manually:** Hold the Timer button for 3 seconds. The OLED counts down 3–2–1, shows **"Touch to Wake Up"**, then enters deep sleep.

**Cancelling sleep countdown:** Touch either button during the countdown. The OLED shows **"Sleep Cancelled"**.

**Auto sleep:** After the configured inactivity timeout (default 10 minutes), the same countdown begins automatically.

**Waking from sleep:** Touch either button. The device boots fully in a few seconds and reconnects to Wi-Fi.

### 12.3 Battery Indicator

The OLED shows a 3-segment battery icon in the top-right corner.

| Segments | Approximate level |
|---|---|
| 3 filled | >60% |
| 2 filled | 30–60% |
| 1 filled | 10–30% |
| 0 filled (flashing) | <10% — charge soon |

**Low battery warning:** If battery voltage is below 3.2 V at boot, the OLED shows a large battery-low message and the device enters deep sleep immediately to prevent damage to the Li-ion cell.

### 12.4 Charging

Charge via the ESP32 board's USB-C port. Most ESP32-S3 boards include an onboard Li-ion charger — the battery charges while connected to USB regardless of whether the scale is switched on.

---

## 13. GaggiMate Bluetooth Integration

CaffePeso implements the same Bluetooth Low Energy (BLE) scale protocol as WeighMyBru², allowing it to work with [GaggiMate](https://github.com/jniebuhr/gaggimate) without any configuration on either device.

**Setup:**

1. In GaggiMate, select **WeighMyBru²** as the Bluetooth scale type.
2. Ensure CaffePeso is powered on and within Bluetooth range.
3. GaggiMate will discover and connect automatically.

**Status indicator:** When a GaggiMate (or other BLE client) is connected, a small **BT** icon appears in the top-right corner of the OLED display.

**What GaggiMate can do:**
- Read real-time weight from CaffePeso

CaffePeso also implements the WeighMyBru² command characteristic, which handles timer start/stop/reset instructions if GaggiMate sends them. Whether GaggiMate uses this in practice depends on the GaggiMate firmware version.

**Note:** The ESP32-S3 has a single shared radio for both BLE and Wi-Fi. They coexist via time-division multiplexing, which works well under normal conditions. However, outgoing HTTP requests (such as those made by the Smart Switch feature) can cause a brief BLE transmission gap of up to a few hundred milliseconds. During this gap, a connected GaggiMate or CaffeRitmo may miss one or two weight updates. For routine BLE scale use this is not noticeable, but if you use the Smart Switch feature alongside a BLE-dependent auto-stop system (GaggiMate, CaffeRitmo), the BLE freeze at the moment of the smart switch trigger can cause the external system to lose flow data and fail to auto-stop correctly. **Do not use the Smart Switch and a BLE-based auto-stop system simultaneously.**

---

## 14. Smart Switch (Shelly Integration)

> **⚠️ Safety notice:** This feature requires fitting a Shelly relay into your machine's mains electrical circuit. This work involves mains voltage and must only be carried out by a competent person who understands the risks. The authors of this project accept no liability for damage, injury, or death arising from electrical work carried out in connection with this feature. **This is entirely optional — CaffePeso is fully functional without it.**

The Smart Switch feature lets CaffePeso stop your espresso machine automatically by controlling a [Shelly](https://www.shelly.com) smart relay fitted inline with the pump or 3-way solenoid valve. No wiring changes to the machine are needed beyond adding the Shelly in series.

### 14.1 Compatibility

CaffePeso uses the **Shelly Gen2/Gen3 RPC API**. Compatible devices include:

- Shelly Plus 1, Plus 1 Mini
- Shelly Pro 1, Pro 1 PM
- Shelly 1 Gen3, 1 Mini Gen3

**Gen1 Shelly devices (original Shelly 1, Shelly 1PM) are not compatible** — they use a different HTTP API and will not respond to CaffePeso's commands.

### 14.2 Hardware Setup

1. Fit a Shelly relay inline with the machine's pump power or 3-way solenoid valve so that switching the relay off stops the pump.
2. Set up the Shelly using the Shelly app — connect it to your 2.4 GHz Wi-Fi network.
3. Find the Shelly's IP address. In the Shelly app, open the device and look under **Settings → Device Information → IP Address**. Alternatively, check your router's connected devices list.
4. **Recommended:** Reserve the Shelly's IP address in your router's DHCP settings so it never changes. If the IP changes, CaffePeso will lose contact with it.
5. Ensure CaffePeso is on the same Wi-Fi network.

### 14.3 Configuration

In the CaffePeso web interface, open **Settings → Smart Switch**:

| Setting | Description |
|---|---|
| **Enable Smart Switch** | Turns the feature on or off. |
| **Shelly IP Address** | The local IP address of the Shelly relay (e.g. `192.168.1.42`). |

Save settings. CaffePeso will send a relay-ON command at boot and each time the scale is armed, to ensure a known state.

### 14.4 How It Works

When armed with a dose weight and target ratio configured, CaffePeso monitors weight and flow rate during the shot and sends a relay-OFF command to the Shelly when the projected final yield is about to reach the target. The trigger formula is:

```
trigger_weight = target_weight − (flow_rate × after_stop_time)
```

**After-Stop Time (AST)** is the number of seconds of continued drip after the pump stops. CaffePeso learns this automatically from each shot and stores one AST value per dose/ratio combination.

- **First shot**: Uses a conservative default of 1.5 s. This intentionally fires slightly early to ensure there is measurable weight gain for the learning system to work with.
- **Subsequent shots**: AST is refined using an exponential weighted moving average (75% old, 25% new) so accuracy improves gradually.

### 14.5 Relay Safety Interlock

After the relay turns off, CaffePeso enters a **post-trigger hold** state:

- The relay stays off even if the scale is re-armed, until you explicitly release the hold.
- To release: perform a **hold-tare** (press and hold the tare button for ~2 s) while the timer is stopped.
- This prevents the pump accidentally restarting mid-session if the scale auto-arms.

### 14.6 Resetting the Learning Data

If your grind, dose, or machine changes significantly, reset the learned AST data so CaffePeso starts fresh:

In the web interface: **Settings → Smart Switch → Reset Learning Data**.

### 14.7 Wi-Fi / BLE Limitation

The smart switch HTTP call and BLE scale output share the same radio. At the moment CaffePeso sends the relay-OFF command, BLE weight transmission pauses for up to a few hundred milliseconds. This means:

- **Do not use the Smart Switch and a BLE-based auto-stop system (GaggiMate, CaffeRitmo) at the same time.** The BLE freeze will cause the external system to lose flow data at the critical moment.
- Wi-Fi power-save mode is always active (required for battery life). This adds 4–400 ms of latency to each HTTP call. The predictive AST algorithm compensates for typical latency, but extreme latency spikes (>400 ms) may cause the relay to fire slightly late.

---

## 15. Troubleshooting

### Scale reads incorrectly after setup

Recalibrate using a known reference weight. See [Section 10.1](#101-scale-calibration).

### Scale drifts slowly when nothing is on it

A 10-second auto-zero correction runs in the background whenever the timer is stopped and weight is within ±0.3 g. If drift is more than ~0.3 g, tap Tare to re-zero manually.

### Timer starts on its own without drips

Check that the load cell is firmly mounted and the scale platform is not vibrating from machine operation. Reduce **Brewing Detection Threshold** in Filtering Settings if false triggers persist.

### Auto Re-arm fires when pouring milk

This can occur if milk is poured in a fast slug that passes through the cup weight window. The REARM\_STEP\_THRESHOLD (8 g per update cycle) is designed to block gradual pours. If your milk jug passes through the window in a single large step, consider disabling Auto Re-arm and arming manually between milk drinks.

### Device not found on Wi-Fi

- Check the IP address on the OLED at boot.
- If no IP is shown, the device is in AP mode — connect to the **CaffePeso** AP and reconfigure Wi-Fi credentials.
- Assign a static DHCP lease on your router to avoid address changes.

### Web interface not loading (blank page / 404)

The filesystem image (web files) may not have been uploaded. Flash the filesystem using the [flash page](https://bitbarista.github.io/CaffePeso/flash.html) or via PlatformIO:
```bash
pio run -e esp32s3-supermini --target uploadfs
```

### OTA update fails or device does not reboot

- Ensure you selected the correct `.bin` file for your board.
- Do not close the browser tab during upload.
- If the device appears unresponsive after a failed OTA, reflash via USB using the flash page.

### Factory reset

Hold the Tare button while powering on (slide the power switch while touching the tare pad). All Wi-Fi credentials are cleared and the device restarts in AP mode. Scale calibration and all other settings are preserved.

---

## Appendix A — Shot Quality Guide

| Measurement | Typical espresso range |
|---|---|
| Dose | 14–22 g |
| Yield | 28–50 g |
| Brew ratio | 1:1.5 – 1:3.0 |
| Brew time | 25–35 s |
| Peak flow rate | 1.5–3.0 g/s |

---

## Appendix B — Attribution

CaffePeso is a derivative of [WeighMyBru²](https://github.com/031devstudios/weighmybru2) by 031devstudios, licensed under [CC BY-NC-SA 4.0](https://creativecommons.org/licenses/by-nc-sa/4.0/).

This derivative is also released under [CC BY-NC-SA 4.0](https://creativecommons.org/licenses/by-nc-sa/4.0/).

---

*Built with care by a home espresso enthusiast. Not affiliated with any espresso machine manufacturer.*

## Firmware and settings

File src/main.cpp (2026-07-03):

#include <WiFi.h>
#include <ESPAsyncWebServer.h>
#include <LittleFS.h>
#include <ESPmDNS.h>
#include <esp_sleep.h>
#include <esp_system.h>
#include <Preferences.h>
#ifdef ESP_IDF_VERSION_MAJOR
    #include "esp_wifi.h"
    #include "esp_err.h"
#endif
#include "WebServer.h"
#include "Scale.h"
#include "WiFiManager.h"
#include "FlowRate.h"
#include "Calibration.h"
#include "BluetoothScale.h"
#include "TouchSensor.h"
#include "Display.h"
#include "PowerManager.h"
#include "BatteryMonitor.h"
#include "BoardConfig.h"
#include "Version.h"
#include "SmartSwitch.h"
#include "Buzzer.h"

// Board-specific pin configuration
uint8_t dataPin = HX711_DATA_PIN;     // HX711 Data pin
uint8_t clockPin = HX711_CLOCK_PIN;   // HX711 Clock pin  
uint8_t touchPin = TOUCH_TARE_PIN;    // Touch sensor for tare
uint8_t sleepTouchPin = TOUCH_SLEEP_PIN;  // Touch sensor for sleep functionality
uint8_t batteryPin = BATTERY_PIN;     // Battery voltage monitoring
uint8_t sdaPin = I2C_SDA_PIN;         // I2C Data pin for display
uint8_t sclPin = I2C_SCL_PIN;         // I2C Clock pin for display
float calibrationFactor = 4195.712891;
Scale scale(dataPin, clockPin, calibrationFactor);
FlowRate flowRate;
BluetoothScale bluetoothScale;
TouchSensor touchSensor(touchPin, &scale);
Display oledDisplay(sdaPin, sclPin, &scale, &flowRate);
PowerManager powerManager(sleepTouchPin, touchPin, &oledDisplay);
BatteryMonitor batteryMonitor(batteryPin);
SmartSwitch smartSwitch;
Buzzer buzzer(BUZZER_PIN, BUZZER_PIN_INV, BUZZER_LEDC_CHANNEL, BUZZER_RESONANT_HZ, BUZZER_DIFFERENTIAL);

// --- Crash diagnostics ------------------------------------------------------
// Captured at boot and persisted to NVS so the reason for an unexpected reset
// (e.g. a brownout while the buzzer plays) survives the *next* reset — important
// on the ESP32-S3 because opening the USB serial port itself triggers a reset,
// which would otherwise overwrite the live esp_reset_reason(). Surfaced over
// WiFi via /api/device/info so no USB connection is needed to read it.
esp_reset_reason_t g_lastReset = ESP_RST_UNKNOWN;
uint32_t           g_bootCount = 0;
String             g_resetHistory; // most-recent-first CSV of reset-reason codes

// HX711 stall self-heal logging — persisted to NVS so recoveries can be reviewed
// after the fact (e.g. after a shot session) without watching a live sweep.
uint32_t           g_hxRecovTotal = 0;  // lifetime recovery count across all boots
String             g_hxRecovLog;        // most-recent-first CSV of "boot#@<uptime>s" markers

const char* resetReasonStr(esp_reset_reason_t r) {
  switch (r) {
    case ESP_RST_POWERON:   return "Power-on";
    case ESP_RST_EXT:       return "External pin / USB-serial reset";
    case ESP_RST_SW:        return "Software reset";
    case ESP_RST_PANIC:     return "PANIC / exception (firmware bug)";
    case ESP_RST_INT_WDT:   return "Interrupt watchdog";
    case ESP_RST_TASK_WDT:  return "Task watchdog";
    case ESP_RST_WDT:       return "Other watchdog";
    case ESP_RST_DEEPSLEEP: return "Deep-sleep wake";
    case ESP_RST_BROWNOUT:  return "BROWNOUT - power sag (electrical)";
    case ESP_RST_SDIO:      return "SDIO";
    default:                return "Unknown";
  }
}

static void captureResetReason() {
  g_lastReset = esp_reset_reason();
  Preferences diag;
  diag.begin("diag", false);
  g_bootCount = diag.getUInt("boots", 0) + 1;
  diag.putUInt("boots", g_bootCount);

  // Prepend this boot's reason to the history, keep at most 12 entries.
  String hist = diag.getString("rr", "");
  hist = String((int)g_lastReset) + (hist.length() ? "," + hist : "");
  int commas = 0;
  for (int i = 0; i < (int)hist.length(); ++i) {
    if (hist[i] == ',' && ++commas == 12) { hist = hist.substring(0, i); break; }
  }
  diag.putString("rr", hist);

  // Restore the persisted HX711 recovery log/total (same namespace).
  g_hxRecovTotal = diag.getUInt("hx_tot", 0);
  g_hxRecovLog   = diag.getString("hx_log", "");

  diag.end();
  g_resetHistory = hist;

  Serial.printf("[BOOT] #%u reset reason: %s (%d)\n",
                g_bootCount, resetReasonStr(g_lastReset), (int)g_lastReset);
}

// Detect HX711 self-heal recoveries (counted in Scale) and persist them to NVS so
// they survive reboots and can be reviewed later. Debounced to one NVS write per
// 5s so a burst of glitches can't wear flash or stall the loop.
static void logHx711Recoveries() {
  static uint32_t      lastSeen  = 0;
  static unsigned long lastFlush = 0;
  static bool          dirty     = false;

  uint32_t now = scale.getRecoveryCount();
  if (now > lastSeen) {
    g_hxRecovTotal += (now - lastSeen);
    lastSeen = now;
    // Prepend a marker: which boot + seconds into that boot the recovery happened.
    // (No RTC, so this is uptime-relative; boot# groups events per power cycle.)
    // TODO(future): once the scale has real time (NTP-over-WiFi, or a DS3231 RTC),
    // log a wall-clock timestamp here instead of millis()/1000 uptime.

    String ev = String(g_bootCount) + "@" + String(millis() / 1000) + "s";
    g_hxRecovLog = ev + (g_hxRecovLog.length() ? "," + g_hxRecovLog : "");
    int commas = 0;                          // keep the ring at 20 entries
    for (int i = 0; i < (int)g_hxRecovLog.length(); ++i) {
      if (g_hxRecovLog[i] == ',' && ++commas == 20) { g_hxRecovLog = g_hxRecovLog.substring(0, i); break; }
    }
    dirty = true;
  }

  if (dirty && millis() - lastFlush >= 5000) {
    Preferences diag;
    diag.begin("diag", false);
    diag.putUInt("hx_tot", g_hxRecovTotal);
    diag.putString("hx_log", g_hxRecovLog);
    diag.end();
    dirty = false;
    lastFlush = millis();
  }
}

void setup() {
  Serial.begin(115200);
  
  // 80 MHz is the lowest stable frequency for WiFi + BLE on the ESP32-S3.
  // Dropping below this causes radio instability; higher values increase power draw with no benefit here.
  setCpuFrequencyMhz(80);
  Serial.printf("CPU frequency set to: %dMHz for power optimization\n", getCpuFrequencyMhz());

  // Record why we (re)started before anything else can mask it.
  captureResetReason();

  // Version and board identification
  Serial.println("=================================");
  Serial.printf("WeighMyBru² v%s\n", WEIGHMYBRU_VERSION_STRING);
  Serial.printf("Board: %s\n", WEIGHMYBRU_BOARD_NAME);
  Serial.printf("Build: %s %s\n", WEIGHMYBRU_BUILD_DATE, WEIGHMYBRU_BUILD_TIME);
  Serial.printf("Full Version: %s\n", WEIGHMYBRU_FULL_VERSION);
  Serial.printf("Flash Size: %dMB\n", FLASH_SIZE_MB);
  Serial.printf("CPU Frequency: %dMHz (Power Optimized)\n", getCpuFrequencyMhz());
  Serial.println("=================================");
  
  // Link scale and flow rate for tare operation coordination
  scale.setFlowRatePtr(&flowRate);
  
  // Check for factory reset request (hold touch pin during boot)
  pinMode(touchPin, INPUT_PULLDOWN);
  if (digitalRead(touchPin) == HIGH) {
    Serial.println("FACTORY RESET: Touch pin held during boot - clearing WiFi credentials");
    clearWiFiCredentials();
    delay(1000);
  }
  
  // CRITICAL: Initialize BLE FIRST before WiFi to prevent radio conflicts
  Serial.println("Initializing BLE FIRST for GaggiMate compatibility...");
  Serial.printf("Free heap before BLE init: %u bytes\n", ESP.getFreeHeap());
  Serial.printf("Free PSRAM before BLE init: %u bytes\n", ESP.getFreePsram());
  
  try {
    bluetoothScale.begin();  // Initialize BLE without scale reference
    Serial.println("BLE initialized successfully - GaggiMate should be able to connect");
    Serial.printf("Free heap after BLE init: %u bytes\n", ESP.getFreeHeap());
    Serial.printf("Free PSRAM after BLE init: %u bytes\n", ESP.getFreePsram());
  } catch (...) {
    Serial.println("BLE initialization failed - continuing without Bluetooth");
    Serial.printf("Free heap after BLE fail: %u bytes\n", ESP.getFreeHeap());
  }
  
  // Initialize display with error handling - don't block if display fails
  Serial.println("Initializing display...");
  bool displayAvailable = oledDisplay.begin();
  
  if (!displayAvailable) {
    Serial.println("WARNING: Display initialization failed!");
    Serial.println("System will continue in headless mode without display.");
    Serial.println("All functionality remains available via web interface.");
  } else {
    Serial.println("Display initialized - ready for visual feedback");
    // Set reduced brightness for power optimization
    oledDisplay.setBrightness(128);  // 50% brightness vs 255 max
    Serial.println("Display brightness set to 50% for power optimization");
  }
  
  // Log wake-up reason (no delay needed — real init below keeps "Starting" on screen)
  esp_sleep_wakeup_cause_t wakeup_reason = esp_sleep_get_wakeup_cause();
  switch(wakeup_reason) {
    case ESP_SLEEP_WAKEUP_EXT0:    Serial.println("Wakeup: external signal (touch)"); break;
    case ESP_SLEEP_WAKEUP_EXT1:    Serial.println("Wakeup: external signal (RTC_CNTL)"); break;
    case ESP_SLEEP_WAKEUP_TIMER:   Serial.println("Wakeup: timer"); break;
    case ESP_SLEEP_WAKEUP_TOUCHPAD:Serial.println("Wakeup: touchpad"); break;
    default: Serial.println("Cold boot (wakeup cause: " + String(wakeup_reason) + ")"); break;
  }

  // Reset WiFi hardware to clean state then start
  WiFi.disconnect(true);
  WiFi.mode(WIFI_OFF);
  delay(50); // minimal hardware settle
  WiFi.setSleep(true);
  setupWiFiForced();
  Serial.printf("Version: %s\n", ESP.getSdkVersion());
  // Initialize scale with error handling - don't block web server if HX711 fails
  Serial.println("Initializing scale...");
  if (!scale.begin()) {
    Serial.println("WARNING: Scale (HX711) initialization failed!");
    Serial.println("Web server will continue to run, but scale readings will not be available.");
    Serial.println("Check HX711 wiring and connections.");
  } else {
    Serial.println("Scale initialized successfully");
    // Now that scale is ready, set the reference in BluetoothScale
    bluetoothScale.setScale(&scale);
  }
  
  // BLE was initialized earlier - no need to initialize again
  // bluetoothScale.begin(&scale);
  
  // Set bluetooth reference in display for status indicator (if display available)
  if (oledDisplay.isConnected()) {
    oledDisplay.setBluetoothScale(&bluetoothScale);
  }
  
  // Set display reference in bluetooth for timer control
  bluetoothScale.setDisplay(&oledDisplay);
  
  // Set power manager reference in display for timer state synchronization (if display available)
  if (oledDisplay.isConnected()) {
    oledDisplay.setPowerManager(&powerManager);
  }
  
  // Set battery monitor reference in display for battery status (if display available)
  if (oledDisplay.isConnected()) {
    oledDisplay.setBatteryMonitor(&batteryMonitor);
  }

  // Initialize touch sensor
  touchSensor.begin();

  // Initialize power manager
  powerManager.begin();

  // Initialize battery monitor
  batteryMonitor.begin();

  // Check for low battery - prevent boot if voltage too low
  float batteryVoltage = batteryMonitor.getBatteryVoltage();
  if (batteryVoltage < 3.2f && batteryVoltage > 0.1f) { // 3.2V = BATTERY_EMPTY; > 0.1V to ignore missing/disconnected battery
    Serial.printf("CRITICAL: Battery voltage too low (%.2fV) - entering sleep\n", batteryVoltage);
    
    // Show battery low message on display with large, centered formatting
    if (oledDisplay.isConnected()) {
      oledDisplay.showBatteryLowMessage(batteryVoltage, 3000);
    }
    
    delay(3000); // Show message for 3 seconds
    
    // Force clear any display state and sleep immediately
    if (oledDisplay.isConnected()) {
      oledDisplay.clear();
    }
    
    Serial.println("Forcing deep sleep now...");
    esp_deep_sleep_start();
  }
  
  Serial.printf("Battery voltage OK (%.2fV) - continuing boot\n", batteryVoltage);

  // Show ready message once all hardware is initialised
  if (oledDisplay.isConnected()) {
    oledDisplay.showIPAddresses();
  }

  // Link display to touch sensor for tare feedback (if display available)
  if (oledDisplay.isConnected()) {
    touchSensor.setDisplay(&oledDisplay);
  }
  
  // Link flow rate to touch sensor for averaging reset on tare
  touchSensor.setFlowRate(&flowRate);

  // Tell tare sensor which pin is the sleep button so it can suppress
  // false tares caused by capacitive coupling between the adjacent pads
  touchSensor.setSleepPin(sleepTouchPin);

  // Initialize piezo sounder (LEDC tone). Harmless if no disc is connected.
  buzzer.begin();

  smartSwitch.begin();
  // Ensure Shelly relay is ON at boot/wake — clears any stale postTriggerRelayOff
  // state and sends a best-effort ON command so the relay is in a known state.
  smartSwitch.ensureRelayOn();
  setupWebServer(scale, flowRate, bluetoothScale, oledDisplay, batteryMonitor, powerManager, smartSwitch);

  // First-run guidance: only when no cup weight has ever been saved (genuine
  // first boot). setupWebServer() has now restored savedTareWeight from NVS, so
  // this check is reliable. Returning users skip straight to the live screen.
  if (oledDisplay.isConnected() && oledDisplay.getSavedTareWeight() < 5.0f) {
    oledDisplay.showFirstRunHint();
  }

  // Startup chime once everything is up.
  buzzer.trigger(BuzzerEvent::BootReady);
}

void loop() {
  static unsigned long lastWeightUpdate = 0;
  static unsigned long lastWiFiCheck = 0;
  static unsigned long lastDisplayUpdate = 0;
  
  // Update weight at reduced frequency for power optimization
  if (millis() - lastWeightUpdate >= 50) { // Reduced from 20ms to 50ms (20Hz from 50Hz)
    float weight = scale.getWeight();
    flowRate.update(weight);
    lastWeightUpdate = millis();

    // Reset inactivity timer on rapid weight change only (cup placement or active brew).
    // Thermal drift of the HX711 can exceed 0.5g/hour — checking flow rate (g/s)
    // distinguishes real events (>0.3 g/s) from slow drift (~0.0001 g/s).
    static float lastActivityWeight = 0.0f;
    if (fabs(weight - lastActivityWeight) > 0.5f) {
      if (fabsf(flowRate.getFlowRate()) > 0.3f) {
        powerManager.notifyActivity();
      }
      lastActivityWeight = weight;
    }

    // Smart switch: reset brew state when timer returns to idle
    static bool prevBrewIdle = true;
    bool brewIdle = !oledDisplay.isTimerRunning() && !oledDisplay.isTimerPaused();
    if (brewIdle && !prevBrewIdle) {
      smartSwitch.resetForNewBrew();
    }
    prevBrewIdle = brewIdle;

    // Smart switch: check trigger every weight cycle.
    // Snapshot post-trigger state before update so we can detect the moment
    // the relay turns off and show a one-shot OLED prompt.
    bool wasPostTrigger = smartSwitch.isPostTriggerRelayOff();
    smartSwitch.update(
      weight,
      flowRate.getFlowRate(),
      oledDisplay.isTimerRunning() && !oledDisplay.isTimerPaused(),
      oledDisplay.isArmed(),
      oledDisplay.getDoseWeight(),
      oledDisplay.getTargetRatio()
    );
    if (!wasPostTrigger && smartSwitch.isPostTriggerRelayOff()) {
      // Relay just turned off — tell the user what to do next
      oledDisplay.showMessage("Relay off-Hold tare", 3000);
      buzzer.trigger(BuzzerEvent::SmartSwitchFired);
    }

    // Target-yield beep — mirrors the OLED flash (Display.cpp uses the same
    // dose x ratio - 2g threshold). Fire once per brew; rearm when idle.
    static bool tyBeeped = false;
    if (brewIdle) {
      tyBeeped = false;
    } else if (!tyBeeped && oledDisplay.isTimerRunning() && !oledDisplay.isTimerPaused()) {
      float dose  = oledDisplay.getDoseWeight();
      float ratio = oledDisplay.getTargetRatio();
      if (dose > 0.5f && ratio > 0.0f) {
        float threshold = dose * ratio - 2.0f;
        if (threshold > 0.0f && weight >= threshold) {
          buzzer.trigger(BuzzerEvent::TargetYield);
          tyBeeped = true;
        }
      }
    }
  }
  
  static unsigned long lastBLEUpdate = 0;
  
  // Check WiFi status every 30 seconds for debugging
  if (millis() - lastWiFiCheck >= 30000) {
    printWiFiStatus();
    lastWiFiCheck = millis();
  }
  
  // Maintain WiFi AP stability
  maintainWiFi();
  checkPendingWiFiDisable();
  checkPendingShotSave(oledDisplay, scale);
  checkPendingBleDeinit(bluetoothScale);
  
  // Update Bluetooth less frequently to reduce BLE interference and power usage
  if (millis() - lastBLEUpdate >= 100) { // Reduced from 50ms to 100ms (10Hz from 20Hz)
    bluetoothScale.update();
    lastBLEUpdate = millis();
  }
  
  // Update touch sensor
  touchSensor.update();

  // Drive the piezo pattern player (non-blocking).
  buzzer.update();

  // Persist any HX711 self-heal recoveries to NVS (debounced) for later review.
  logHx711Recoveries();

  // Tare beep — fires on every touch tare (tap or hold); strobe self-clears.
  if (touchSensor.wasTareCompleted()) buzzer.trigger(BuzzerEvent::Tare);

  // --- Audible event detection ---
  // Armed / auto-re-armed: poll the strobe set inside Display::arm(), not an
  // isArmed() edge — a re-arm while already armed (true->true) has no edge, and
  // an arm that completes within one loop iteration would be missed.
  if (oledDisplay.wasArmCompleted()) buzzer.trigger(BuzzerEvent::Armed);

  // BLE client connect / disconnect.
  static bool prevBle = false;
  bool bleNow = bluetoothScale.isConnected();
  if (bleNow && !prevBle)      buzzer.trigger(BuzzerEvent::BleConnected);
  else if (!bleNow && prevBle) buzzer.trigger(BuzzerEvent::BleDisconnected);
  prevBle = bleNow;

  // Battery entering low/critical (rising edge only, so it beeps once).
  static bool prevLow = false;
  bool lowNow = batteryMonitor.isLowBattery() || batteryMonitor.isCriticalBattery();
  if (lowNow && !prevLow) buzzer.trigger(BuzzerEvent::BatteryLow);
  prevLow = lowNow;

  // Smart switch safety: re-enable relay only via deliberate hold-tare.
  // wasHoldTareCompleted() strobes true for exactly one loop iteration after
  // a hold-tare fully executes, giving us a clean one-shot check here.
  if (touchSensor.wasHoldTareCompleted() && smartSwitch.isPostTriggerRelayOff()) {
    if (!oledDisplay.isTimerRunning()) {
      if (!smartSwitch.reEnableRelay()) {
        oledDisplay.showMessage("Relay err-check WiFi", 3000);
      }
      // On success the normal inverted "Armed" screen was already shown by
      // the hold-tare itself — no extra message needed.
    } else {
      // Timer is still running (e.g. auto-stop hasn't fired yet after trigger)
      oledDisplay.showMessage("Wait-timer running", 2000);
    }
  }

  // Update power manager
  powerManager.update();
  
  // Update battery monitor
  batteryMonitor.update();
  
  // Update display less frequently for power saving
  if (millis() - lastDisplayUpdate >= 100) { // Reduced display refresh rate to 10Hz
    oledDisplay.update();
    lastDisplayUpdate = millis();
  }
  
  // Increased delay for better power efficiency while maintaining responsiveness
  delay(10); // Optimized delay: 10ms for good responsiveness with power savings
}

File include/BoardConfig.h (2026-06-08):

#ifndef BOARD_CONFIG_H
#define BOARD_CONFIG_H

// Board identification and pin configuration

#ifdef BOARD_SUPERMINI
  #define BOARD_NAME "ESP32-S3-DevKitC-1 (SuperMini)"
  #define BOARD_TYPE_SUPERMINI
  
#elif defined(BOARD_XIAO)
  #define BOARD_NAME "XIAO ESP32S3" 
  #define BOARD_TYPE_XIAO
  
#else
  #define BOARD_NAME "ESP32-S3 (Unknown)"
  #define BOARD_TYPE_SUPERMINI  // Default fallback
  
#endif

// Pin definitions (currently identical for both boards)
#define HX711_DATA_PIN      5   // GPIO5 - HX711 Data pin
#define HX711_CLOCK_PIN     6   // GPIO6 - HX711 Clock pin  
#define TOUCH_TARE_PIN      4   // GPIO4 - Touch sensor for tare (T0)
#define TOUCH_SLEEP_PIN     3   // GPIO3 - Touch sensor for sleep functionality
#define BATTERY_PIN         7   // GPIO7 - Battery voltage monitoring (ADC1_CH6)
#define I2C_SDA_PIN         8   // GPIO8 - I2C Data pin for display
#define I2C_SCL_PIN         9   // GPIO9 - I2C Clock pin for display
#define BUZZER_PIN          2   // GPIO2 - Piezo sounder, non-inverted half. Free, non-strapping on ESP32-S3.
#define BUZZER_PIN_INV      1   // GPIO1 - inverted half (differential/BTL drive). Adjacent to GPIO2 for easy wiring. 255 = single-ended.
// Brownout A/B test: 1 = differential/BTL (loud, GPIO1+GPIO2 antiphase, ~2x swing & current);
// 0 = single-ended (GPIO1 held at GND, GPIO2 drives) ~half the current — NO rewiring needed.
// Flip to 0 and reflash; if the beep-time crashes stop, the cause is electrical (add a series resistor).
#define BUZZER_DIFFERENTIAL 1
#define BUZZER_LEDC_CHANNEL 0   // LEDC channel for the piezo (LEDC is otherwise unused)
#define BUZZER_RESONANT_HZ  4200 // 27mm disc resonant frequency (loudest tone)

// Board-specific configurations
#ifdef BOARD_TYPE_SUPERMINI
  #define FLASH_SIZE_MB       4
  #define BOARD_DESCRIPTION   "ESP32-S3 SuperMini with 4MB Flash"
  
#elif defined(BOARD_TYPE_XIAO)
  #define FLASH_SIZE_MB       8
  #define BOARD_DESCRIPTION   "XIAO ESP32S3 with 8MB Flash"
  
#endif

// Common ESP32-S3 features available on both boards
#define HAS_WIFI            true
#define HAS_BLUETOOTH       true
#define HAS_PSRAM           true
#define HAS_TOUCH_SENSOR    true
#define ADC_RESOLUTION      12    // 12-bit ADC
#define PWM_RESOLUTION      8     // 8-bit PWM

#endif // BOARD_CONFIG_H

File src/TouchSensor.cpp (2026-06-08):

#include "TouchSensor.h"
#include "Scale.h"
#include "Display.h"
#include "FlowRate.h"
#include "WiFiManager.h"

TouchSensor::TouchSensor(uint8_t touchPin, Scale* scale)
    : touchPin(touchPin), scalePtr(scale), displayPtr(nullptr), flowRatePtr(nullptr), touchThreshold(30000),
      lastTouchState(false), lastTouchTime(0), touchStartTime(0), debounceDelay(200),
      longPressDetected(false), delayedTarePending(false), delayedTareTime(0),
      holdTarePending(false), holdFeedbackShown(false), holdWaitingForRelease(false) {
}

void TouchSensor::begin() {
    // Set up the pin as digital input with pull-down resistor for the touch sensor module
    // This prevents false triggers when no touch sensor is connected
    pinMode(touchPin, INPUT_PULLDOWN);
    Serial.println("Digital touch sensor initialized on pin " + String(touchPin) + " with pull-down resistor");
}

void TouchSensor::update() {
    // Suppress tare input while the sleep button is held AND for 500ms after it is
    // released. The two adjacent touch sensor pads couple capacitively: the active-HIGH
    // output on the sleep pad induces a brief spike on the tare pad at the moment of
    // release (HIGH→LOW transition), which is when the coupling peaks.
    if (sleepPin != 255) {
        static unsigned long sleepPinLastHighTime = 0;
        if (digitalRead(sleepPin) == HIGH) {
            sleepPinLastHighTime = millis();
            return;
        }
        if (millis() - sleepPinLastHighTime < 500) return;
    }

    bool currentTouchState = isTouched();
    unsigned long currentTime = millis();
    
    // Check for touch state change with debouncing
    if (currentTouchState != lastTouchState) {
        if (currentTime - lastTouchTime > debounceDelay) {
            if (currentTouchState) {
                // Touch started
                touchStartTime = currentTime;
                longPressDetected = false;
                holdFeedbackShown = false;
                holdWaitingForRelease = false;
                Serial.println("Touch started");
            } else {
                // Touch ended
                if (!longPressDetected) {
                    // Tap: just zero the scale
                    scheduleDelayedTare();
                    Serial.println("Tare button: tap tare");
                } else if (holdWaitingForRelease) {
                    // Hold complete — user just released. Wait HOLD_SETTLE_MS for scale to
                    // settle (no press force), then read cup weight and execute tare+arm.
                    holdWaitingForRelease = false;
                    holdTarePending    = true;
                    delayedTarePending = true;
                    delayedTareTime    = currentTime + HOLD_SETTLE_MS;
                    Serial.println("Hold tare: button released, settling...");
                }
                longPressDetected = false;
                Serial.println("Touch ended");
            }
            lastTouchState = currentTouchState;
            lastTouchTime = currentTime;
        }
    }

    // During-hold: show "Taring..." at 500ms, show "Release!" at 1500ms
    if (currentTouchState && !longPressDetected) {
        unsigned long held = currentTime - touchStartTime;
        if (held >= HOLD_FEEDBACK_MS && !holdFeedbackShown) {
            holdFeedbackShown = true;
            if (displayPtr != nullptr) displayPtr->showTaringMessage();
            Serial.println("Hold tare: feedback shown, keep holding");
        }
        if (held >= HOLD_TARE_MS && !holdWaitingForRelease) {
            holdWaitingForRelease = true;
            longPressDetected = true; // prevents tap path on release
            if (displayPtr != nullptr) displayPtr->showReleaseMessage();
            Serial.println("Hold tare: threshold reached, waiting for release");
        }
    }

    // Check for pending delayed tare
    checkDelayedTare();
}

void TouchSensor::setTouchThreshold(uint16_t threshold) {
    touchThreshold = threshold;
    Serial.println("Touch threshold set to: " + String(touchThreshold));
}

uint16_t TouchSensor::getTouchValue() {
    // For digital touch sensor modules, return the digital state as 0 or 1
    return digitalRead(touchPin) ? 1 : 0;
}

bool TouchSensor::isTouched() {
    // For digital touch sensor modules, check if the pin is HIGH
    // Most touch sensor modules output HIGH when touched
    bool touched = digitalRead(touchPin) == HIGH;
    
    // Debug: log unexpected HIGH readings when no sensor should be connected
    static unsigned long lastDebugTime = 0;
    if (touched && millis() - lastDebugTime > 5000) { // Log every 5 seconds max
        Serial.println("DEBUG: Touch pin GPIO" + String(touchPin) + " reading HIGH - check for floating pin or connected sensor");
        lastDebugTime = millis();
    }
    
    return touched;
}

void TouchSensor::setDisplay(Display* display) {
    displayPtr = display;
}

void TouchSensor::setFlowRate(FlowRate* flowRate) {
    flowRatePtr = flowRate;
}

void TouchSensor::handleTouch() {
    if (scalePtr != nullptr) {
        Serial.println("Touch detected! Taring scale...");
        
        // Show tare message on display if available
        if (displayPtr != nullptr) {
            displayPtr->showTaringMessage();
        }
        
        scalePtr->tare();
        Serial.println("Scale tared successfully");
        
        // Reset timer when manual tare is pressed
        if (displayPtr != nullptr) {
            displayPtr->resetTimer();
            Serial.println("Timer reset with manual tare");
        }
        
        // Reset flow rate averaging for fresh brew
        if (flowRatePtr != nullptr) {
            flowRatePtr->resetTimerAveraging();
            Serial.println("Flow rate averaging reset for fresh brew");
        }
        
        // Show completion message on display if available
        if (displayPtr != nullptr) {
            displayPtr->showTaredMessage();
        }
    } else {
        Serial.println("Error: Scale pointer is null");
    }
}

void TouchSensor::scheduleDelayedTare() {
    holdTarePending = false; // tap, not hold

    if (displayPtr != nullptr) {
        displayPtr->resetNegativeFlag(); // clear direct re-arm path immediately — prevents armed state during the 1.5s delay
        displayPtr->showTaringMessage();
        Serial.println("Taring message displayed");
    }

    Serial.println("Scheduling delayed tare in 1.5 seconds...");
    delayedTarePending = true;
    delayedTareTime = millis() + TARE_DELAY;
}
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

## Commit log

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2025-08-18 Fix WiFi issue: Move battery pin from GPIO1 to GPIO7
    - GPIO1 is a strapping pin that interferes with WiFi initialization
    - GPIO7 (ADC1_CH6) is safer and provides same ADC functionality
    - This should resolve AP mode and STA connection issues
    [main.cpp]
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2025-08-18 feat: Complete battery monitoring system with calibration and mobile UI
    - Add comprehensive BatteryMonitor class with Li-ion voltage management
    - Implement 100kΩ voltage divider on GPIO7 with ADC calibration
    - Add battery calibration API endpoints (GET/POST) with persistent storage
    - Create user-friendly calibration interface in web dashboard
    - Add phone-style 4-segment battery indicator in top-right corner
    - Fix WiFi/BLE coexistence issue (WiFi sleep enabled for dual radio)
    - Update dashboard title from 'WeighMyBru Dashboard' to 'Dashboard'
    - Add real-time battery status with color-coded indicators
    - Support voltage range 2.9V-4.2V with smart percentage calculation
    - Include battery debug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
    [BatteryMonitor.cpp, BatteryMonitor.h, WebServer.cpp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]
2025-08-18 Implement comprehensive battery monitoring system
    Features added:
    - Complete BatteryMonitor class with Li-ion voltage management
    - GPIO7 ADC integration with 100kΩ voltage divider support
    - 4-segment OLED battery indicator with critical battery flashing
    - Web-based battery calibration interface on /calibration page
    - Battery status API endpoints (GET/POST /api/battery)
    - Mobile-responsive dashboard with phone-style battery indicator
    - WiFi/BLE coexistence fixes with WiFi sleep mode
    - Clean OLED display with pixel-art Bluetooth icon
    - Persistent calibration storage in EEPROM
    - Critical battery warning with solid white flashing animation
    Hardware:
    - Battery monitoring on GPIO7 with voltage d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
    [Display.cpp]
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2025-08-23 Implement Bean Conqueror BLE integration
    - Add timer control commands via BLE (start/stop/reset)
    - Enhanced command processing with proper protocol handling
    - Add display reference to BluetoothScale for timer control
    - Add comprehensive documentation for Lars
    - All required API functions now implemented:
    * Weight send (existing)
    * Taring (enhanced)
    * Timer start/stop/reset (new)
    Ready for Bean Conqueror integration testing.
    [BluetoothScale.cpp, main.cpp]
2025-08-23 Fix Bean Conqueror integration issues
    - Fix timer pause/resume functionality: Timer now properly resumes from paused state across BLE and web interfaces
    - Fix weight data format: Change from WeighMyBru protocol to simple 4-byte float32 little-endian format expected by Bean Conqueror
    - Update documentation with correct weight format specifications
    Both timer control and weight display now work correctly with Bean Conqueror app
    [BluetoothScale.cpp, Display.cpp]
2025-08-25 Implement dual BLE characteristics for Bean Conqueror and GaggiMate compatibility
    - Add separate weight characteristics for each app format
    - GaggiMate: 6E400002 (WeighMyBru protocol, 20 bytes)
    - Bean Conqueror: 6E400004 (simple float32, 4 bytes)
    - Maintain backward compatibility for GaggiMate
    - Add error handling to prevent crashes
    - Update documentation with correct UUID mapping
    [BluetoothScale.cpp]
2025-08-25 Fix boot loop and BLE message processing issues
    - Add BLE power reduction to prevent boot loops on battery power
    - Filter incoming messages to only process WeighMyBru protocol (Product 0x03)
    - Ignore GaggiMate's unknown messages that were causing infinite loops
    - Reduce BLE TX power levels for better battery stability
    - Add error handling for message validation
    This should resolve both the boot loop when unplugged and the repetitive BLE message spam.
    [BluetoothScale.cpp]
2025-08-25 Fix under-voltage boot issue with lower-power BLE initialization
    - Reduce BLE TX power to minimum (ESP_PWR_LVL_N12) during initialization
    - Add global BLE power reduction during boot to reduce current draw
    - Add memory monitoring for debugging
    - Add power settling delay between BLE init steps
    This should allow booting on batteries with lower voltage (3.99V) that were causing boot loops due to voltage sag during high-current BLE initialization.
    [BluetoothScale.cpp, main.cpp]
2025-08-25 Fix BLE connectivity issues for dual app support
    - Increase BLE power from -12dBm to -3dBm for better connectivity range
    - Accept messages from both GaggiMate (Product 0x02) and WeighMyBru (Product 0x03)
    - Maintain power optimization during boot to prevent under-voltage issues
    - Enable simultaneous Bean Conqueror and GaggiMate compatibility
    This resolves the connectivity issues where GaggiMate couldn't read weights
    after the under-voltage boot fix implementation.
    [BluetoothScale.cpp]
2025-08-25 Optimize battery voltage scale for ESP32 operation
    - Adjust voltage thresholds for 700mAh/1200mAh Li-ion batteries
    - Set reliable boot threshold at 4.0V (75% instead of old ~95%)
    - Update BATTERY_GOOD from 3.8V to 4.0V for ESP32 stability
    - Update BATTERY_CRITICAL from 3.0V to 3.2V (may not boot reliably)
    - Update BATTERY_EMPTY from 2.9V to 3.0V (protection threshold)
    - Add ESP32-specific status descriptions with boot reliability info
    This provides more accurate battery percentages that reflect actual
    ESP32 operating requirements under BLE load conditions.
    [BatteryMonitor.cpp, BatteryMonitor.h]
2025-08-25 Set conservative battery empty threshold at 3.5V
    - Change BATTERY_EMPTY from 3.0V to 3.5V for safer operation
    - Change BATTERY_CRITICAL from 3.2V to 3.5V (charge immediately)
    - Provides better safety buffer above protection circuit threshold
    - Ensures user gets early warning before ESP32 becomes unreliable
    This prevents users from running the battery too low and gives
    more time to charge before encountering boot issues.
    [BatteryMonitor.cpp, BatteryMonitor.h]
2025-08-25 Fix display layout: swap timer and flow rate positions
    - Move timer to bottom left (fixed position)
    - Move flow rate to bottom right (fixed position)
    - Remove Bluetooth adjustment for flow rate positioning
    - Flow rate no longer shifts when Bluetooth connects/disconnects
    This resolves the issue where flow rate would move left when the
    Bluetooth indicator appeared, even though they are in different
    areas of the display (top vs bottom).
    [Display.cpp]
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2025-08-27 Optimize WiFi power consumption with smart mode switching
    Key improvements:
    - Prioritize STA mode connection when credentials exist for lower power consumption
    - Only fallback to AP mode if no credentials stored or STA connection fails
    - Stop AP broadcasting once STA successfully connects (significant power savings)
    - Immediate connection attempt when new credentials entered (no reboot required)
    - Smart fallback to AP mode if STA connection fails during credential entry
    - Enhanced user feedback with JSON responses showing connection status and IP
    Technical changes:
    - Modified setupWiFi() to try STA first, only start AP as fallback
    - Added attemptSTAConnection() for immediate connection with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
    [WebServer.cpp, WiFiManager.cpp, main.cpp]
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2025-08-27 Fix WiFi maintenance breaking STA-only mode + Status page layout improvements
    Critical WiFi Fix:
    - Fixed maintainWiFi() function incorrectly switching from STA back to AP mode
    - Old logic assumed dual AP+STA mode and 'restored' AP when seeing STA-only mode
    - New logic respects STA-only mode for power optimization
    - Only switches to AP mode if STA connection actually fails
    - Intelligent STA reconnection attempts before AP fallback
    - Maintains intended power-saving behavior
    Status Page Layout:
    - Removed 'BAT:' prefix from battery percentage (cleaner display)
    - Moved IP address to bottom of display (y=24 on 32-pixel screen)
    - Better space utilization and visual hierarchy
    - Battery shows as '85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
    [Display.cpp, WiFiManager.cpp]
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2025-08-27 Implement custom weight display with compact decimal point
    Problem solved:
    - Weight display with 3 digits (e.g., 100.5g) was crashing into timer/flow rate on right
    - Large size-3 decimal point was taking too much horizontal space
    - Layout became cramped and unreadable at higher weights
    Solution implemented:
    - Custom weight rendering using mixed text sizes for optimal space usage
    - Integer part: Size 3 text for prominence (e.g., '100')
    - Decimal point: Size 1 text positioned at baseline for minimal footprint
    - Decimal digit: Size 2 text for good readability (e.g., '5')
    - Negative sign: Size 3 text when needed (e.g., '-12')
    Technical details:
    - Split weight into integer and decimal parts pro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
    [Display.cpp]
2025-08-27 Fix message timing and optimize user experience
    Message duration improvements:
    - Startup 'WeighMyBru Ready' message reduced from 3 seconds to 1 second for faster boot
    - 'Scale Tared!' message reduced from 2 seconds to 1 second for quicker feedback
    Taring sequence bug fix:
    - Fixed broken taring message timing that caused premature display transitions
    - 'Taring . . .' message now properly displays for full 2 seconds during tare process
    - 'Scale Tared!' message uses specific 1-second duration override
    - Eliminated brief return to main display between taring messages
    Technical implementation:
    - Kept default messageDuration at 2000ms for taring process stability
    - Added messageDuration override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
    [Display.cpp]
2025-08-27 Fix taring message sequence bug - proper duration handling
    Problem resolved:
    - First tare worked correctly but subsequent tares were broken
    - showTaredMessage() was permanently modifying messageDuration from 2000ms to 1000ms
    - Caused 'Taring . . .' message on subsequent tares to show for only 1 second
    - Result: premature return to main display, then 'Scale Tared!' appeared
    Root cause:
    - messageDuration class member was being modified and not restored
    - Affected all subsequent message timing, not just tared messages
    - Removed permanent messageDuration modification from showTaredMessage()
    - Added smart duration logic in timeout check using effectiveDuration
    - Detects 'T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
    [Display.cpp]
2025-08-28 Fix BLE stability and weight display rounding issues
    BLE Stability Improvements:
    - Increase BLE transmission power from -3dBm to 0dBm for stronger signal
    - Optimize main loop delay from 5ms to 25ms to reduce system overload
    - Throttle BLE updates from every 5ms to every 50ms (200Hz → 20Hz)
    - Reduce weight reading frequency from 10ms to 20ms (100Hz → 50Hz)
    - Maintains excellent responsiveness while reducing BLE interference
    Weight Display Bug Fix:
    - Fix decimal rounding carry-over issue (4.95g showing as '4.10' instead of '5.0')
    - Add proper carry-over handling when decimal part rounds to 10 or higher
    - Ensures correct progression: 4.7 → 4.8 → 4.9 → 5.0
    Root Cause Analysis:
    - BLE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
    [BluetoothScale.cpp, Display.cpp, main.cpp]
2025-08-28 Implement compact decimal points and T/F labels for timer and flow rate
    Display Improvements:
    - Apply compact decimal point rendering to timer and flow rate (matching weight display)
    - Add 'T' and 'F' labels for clear identification of timer vs flow rate
    - Position labels at far right edge for consistent alignment regardless of number size
    Compact Decimal Implementation:
    - Timer: Size 2 integer + Size 1 decimal point + Size 1 decimal digit
    - Flow rate: Size 2 integer + Size 1 decimal point + Size 1 decimal digit
    - Proper carry-over handling (e.g., 12.95 → 13.0, not 12.10)
    - Significant space savings with smaller decimal points
    Label Positioning System:
    - 'T' label: Fixed at far right edg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
    [Display.cpp]
2025-08-28 Replace status underlines with rectangle borders
    Status Indicator Enhancement:
    - Change underlines to complete rectangle borders around 'HX711' and 'BT' text
    - Add proper spacing so borders don't touch the text (1px top, 2px left/right/bottom)
    - Apply to both status page and main screen Bluetooth indicator
    Rectangle Specifications:
    - HX711: 34x10 rectangle starting at (48,-1) with proper text spacing
    - BT: 16x10 rectangle starting at (108/113,-1) with proper text spacing
    - Rectangles only appear when devices are connected
    - Top line positioned 1 pixel above text, left line 2 pixels before text
    Visual Improvement:
    - Professional rectangular borders instead of simple underlines
    - Clean spaci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
    [Display.cpp]
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2025-08-31 Implement ESP32-S3 SuperMini WiFi antenna fix
    Hardware Issue Solution:
    - Fixes common 'touch antenna to work' problem on SuperMini boards
    - Implements maximum WiFi TX power compensation for poor antenna design
    - Based on proven solution from ESP32 forums (esp32.com/viewtopic.php?t=41895)
    Technical Implementation:
    ✅ Dual-level power boost: Arduino framework (19.5dBm) + ESP-IDF (10dBm)
    ✅ Power settings reapplied after WiFi mode switches (mode change resets power)
    ✅ Configurable enable/disable via ENABLE_SUPERMINI_ANTENNA_FIX define
    ✅ Automatic fallback if ESP-IDF functions unavailable
    ✅ Compatible with BLE coexistence (maintains WiFi sleep mode)
    Code Structure:
    - applySuperMiniAnte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
    [WiFiManager.cpp]
2025-09-01 Remove all emojis from serial monitor output
    Serial Output Cleanup:
    - Removed all Unicode emoji characters from WiFiManager serial messages
    - Replaced emoji prefixes with plain text equivalents
    - Maintained all functionality while improving compatibility
    Changes Applied:
    - setupWiFi(): Cleaned connection status messages
    - maintainWiFi(): Removed emoji status indicators
    - attemptSTAConnection(): Plain text connection feedback
    - switchToAPMode(): Simple AP mode switching messages
    - applySuperMiniAntennaFix(): Clean antenna fix status output
    Benefits:
    - Better compatibility with all serial terminals
    - Cleaner log parsing and automated processing
    - Consistent plain text formatting
    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
    [WiFiManager.cpp, main.cpp]
2025-09-01 Add WiFi and Bluetooth signal strength monitoring
    Signal Strength Features:
    - Real-time WiFi signal strength (RSSI) monitoring in dashboard header
    - Bluetooth signal strength display for connected devices
    - Color-coded indicators (Green/Orange/Red) based on signal quality
    - Signal strength values shown in dBm next to connection icons
    API Enhancements:
    - New /api/signal-strength endpoint for detailed connection info
    - Enhanced dashboard API with signal strength data
    - WiFi connection details (SSID, channel, TX power, IP info)
    - Bluetooth connection status and signal quality
    Web Interface Improvements:
    - Moved signal indicators to header next to battery/BT icons
    - Fixed filter state display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
    [BluetoothScale.cpp, WebServer.cpp, WiFiManager.cpp]
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2025-09-17 Convert from ESP32 BLE Arduino to NimBLE for GaggiMate compatibility
    - Replace ESP32 BLE Arduino library with h2zero/NimBLE-Arduino@^1.4.0
    - Update all BLE includes: BLEDevice -> NimBLEDevice, BLEServer -> NimBLEServer, etc.
    - Convert BLE property constants: BLECharacteristic::PROPERTY_* -> NIMBLE_PROPERTY::*
    - Update callback function signatures to use NimBLE types
    - Update descriptors: BLE2902 -> NimBLE2902
    - This should improve GaggiMate discovery compatibility as both will use same BLE stack
    [BluetoothScale.cpp]
2025-09-17 Convert from BLE Arduino to NimBLE for GaggiMate compatibility
    - Replace ESP32 BLE Arduino with h2zero/NimBLE-Arduino@^1.4.0
    - Update all BLE types: BLEDevice -> NimBLEDevice, BLEServer -> NimBLEServer, etc.
    - Convert BLE property flags to NIMBLE_PROPERTY format
    - Fix descriptor creation for NimBLE (use NimBLEDescriptor instead of NimBLE2902)
    - Update callback function signatures for NimBLE compatibility
    - Should resolve GaggiMate scanning/discovery issues by using same BLE stack
    [BluetoothScale.cpp]
2025-09-17 Fix NimBLE descriptor creation syntax
    - Use createDescriptor() method instead of addDescriptor(new NimBLEDescriptor())
    - Provide correct parameters: UUID, properties, and max length (2 bytes for 2902)
    - Should resolve compilation errors for descriptor creation
    [BluetoothScale.cpp]
2025-09-17 Fix NimBLE boot loop and BLE device name issues
    - Remove manual 0x2902 descriptor creation (NimBLE auto-creates these)
    - Enable scan response and explicitly set advertising name to show full 'WeighMyBru'
    - Resolves boot loop caused by descriptor assertion failure
    - Fixes BLE device name truncation from 'WeighMyB' to full 'WeighMyBru'
    - NimBLE conversion now stable and ready for GaggiMate compatibility testing
    [BluetoothScale.cpp]
2025-09-21 Add filesystem check and user prompt for missing LittleFS
    - Display clear error message when LittleFS.begin() fails
    - Prompt user to run 'pio run -t uploadfs' to upload filesystem
    - Include alternative PlatformIO IDE instructions
    - Explain that scale continues to work but web interface is unavailable
    - Improves user experience by providing clear fix instructions
    [WebServer.cpp]
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2025-09-28 Add WiFi power management for battery saving
    Features implemented:
    - WiFi on/off toggle functions (enableWiFi, disableWiFi, toggleWiFi)
    - Persistent WiFi enabled state stored in preferences
    - Web interface controls in settings page with live status updates
    - Touch sensor long press (3 seconds) to toggle WiFi
    - Display shows 'WiFi: OFF' when disabled for battery saving
    - API endpoints: /api/wifi-status, /api/wifi-toggle, /api/wifi-enable
    - WiFi setup and maintenance skip when disabled
    - Automatic WiFi mode restoration when re-enabled
    This feature allows users to completely disable WiFi to extend battery life
    when not needed, while preserving saved credentials and easy re-enabling.
    [Display.cpp, TouchSensor.cpp, WebServer.cpp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]
2025-09-28 Fix WiFi disable crash - proper TCP/IP stack cleanup
    Problem: Boot loop when disabling WiFi through web interface caused by
    TCP/IP stack accessing invalid network state after WiFi.mode(WIFI_OFF)
    Solution:
    - Graceful connection cleanup before disabling WiFi
    - Separate handling for STA vs AP mode disconnection
    - Added delay to allow HTTP responses to complete
    - Send response before disabling WiFi to prevent connection loss
    - Proper WiFi.disconnect() and WiFi.softAPdisconnect() sequence
    This prevents the tcpip_api_call error and ensures smooth WiFi power
    management without system crashes.
    [WebServer.cpp, WiFiManager.cpp]
2025-09-28 feat: Complete WiFi power management implementation
    - Add WiFi enable/disable functionality for battery savings
    - Implement long press (5s) tare button for WiFi toggle
    - Add web interface controls for WiFi management
    - Create proper web server lifecycle management
    - Add WiFi status display on OLED ("WiFi: OFF" when disabled)
    - Implement persistent WiFi state storage in preferences
    - Add graceful TCP/IP stack cleanup to prevent boot crashes
    - Clean up dual-button complexity for simpler UX
    - Maintain compatibility with existing tare/status functionality
    New Features:
    - 5-second long press tare button toggles WiFi ON/OFF
    - Web interface "Turn Off WiFi" button (can only turn back on via hardwar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
    [Display.cpp, Display.h, PowerManager.cpp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]
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2025-10-02 fix: Enable WiFi power management globally for consistent battery optimization
    - Move WiFi.setSleep(true) to main.cpp setup() before setupWiFi() call
    - Ensures power management is always active regardless of WiFi state
    - Remove duplicate WiFi.setSleep(true) call from setupWiFi() function
    - Fixes power consumption inconsistency where starting with WiFi OFF used more power than STA→OFF transition
    - Should provide consistent ~80mA baseline power consumption for all WiFi states
    Resolves user-reported issue where WiFi OFF mode consumed 120mA when starting disabled vs 80mA when transitioning from STA to OFF mode.
    [WiFiManager.cpp, main.cpp]
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2025-11-12 ✨ Improve filesystem error handling
    - Replace repetitive NVS error messages with informative one-time guidance
    - Add filesystem availability checking to prevent error spam
    - Implement clear startup message explaining missing LittleFS and how to fix
    - Gracefully handle missing filesystem while maintaining functionality
    - Cache WiFi preferences in memory when NVS unavailable
    Resolves issue where missing filesystem caused continuous
    "ERROR: Failed to load WiFi enabled state" messages
    [WiFiManager.cpp]
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2025-12-18 feat: Implement comprehensive power optimization reducing consumption to 0.05A
    - Reduce CPU frequency from 240MHz to 80MHz (66% power reduction)
    - Optimize update intervals: weight 20ms→50ms, BLE 50ms→100ms, display 100ms
    - Implement dual WiFi state persistence (NVS + EEPROM backup)
    - Fix WiFi power management with proper initialization/shutdown sequence
    - Add forced WiFi setup function to replicate tare button behavior
    - Ensure consistent 0.05A power consumption when WiFi disabled
    - Maintain BLE functionality when WiFi disabled for coffee app connectivity
    Power consumption results:
    - WiFi enabled: ~90mA (optimized from 100mA)
    - WiFi disabled: 0.05A (consistent after power cycling)
    - Ba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
    [WiFiManager.cpp, main.cpp]
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2025-12-18 feat: Add WiFi network scanner and UI improvements
    - Implement WiFi network scanning with /api/wifi-scan endpoint
    - Add scanWiFiNetworks() function with JSON response including RSSI, encryption, channel
    - Create interactive network selection UI with signal strength indicators
    - Add color-coded signal bars (green/orange/red) with progressive fill levels
    - Implement clickable network list with hover effects and pointer cursor
    - Enhance WiFi form feedback with simplified reboot message
    - Improve user experience with one-click network selection
    - Sort networks by signal strength for better usability
    [WebServer.cpp, WiFiManager.cpp]
2026-01-15 Fix GaggiMate BLE discovery issue
    Remove scan response advertising to prevent double discovery callbacks.
    GaggiMate was receiving two callbacks (once without name, once with name)
    which broke scale discovery. Now device name is included in initial
    advertising packet for single callback compatibility.
    Fixes: SuperMini users unable to discover WeighMyBru in GaggiMate
    [BluetoothScale.cpp]
2026-01-21 Fix GaggiMate BLE discovery issues for ESP32-S3 SuperMini
    - Remove redundant advertising->setName() call to prevent 31-byte payload overflow
    - Fix connection interval preferences from invalid 0x0 to proper 7.5ms-22.5ms range
    - Resolves discovery failures on certain ESP32-S3 SuperMini variants
    [BluetoothScale.cpp]
2026-01-25 Implement battery management improvements
    - Rescale battery voltage thresholds (3.2V = 0%, 3.4V = critical)
    - Add low battery protection during startup
    - Display "Bat Low X.XV" message when voltage < 3.2V
    - Force deep sleep mode to prevent battery damage
    - Update percentage calculation for new voltage range
    [BatteryMonitor.cpp, BatteryMonitor.h, main.cpp]
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

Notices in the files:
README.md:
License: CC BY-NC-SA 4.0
